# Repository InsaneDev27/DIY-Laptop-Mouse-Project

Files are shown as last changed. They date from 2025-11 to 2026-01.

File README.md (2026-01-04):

# DIY-Laptop-Mouse-Project

The Laptop Mouse Project (LMP) is a DIY solution for discomfort caused by prolonged use of laptop trackpads. The LMP offers an ergonomic alternative to a typical mouse or trackpad and clamps to the side of laptops for stability and comfort. It is mostly 3-D printable, and all electronics can be found online.

\
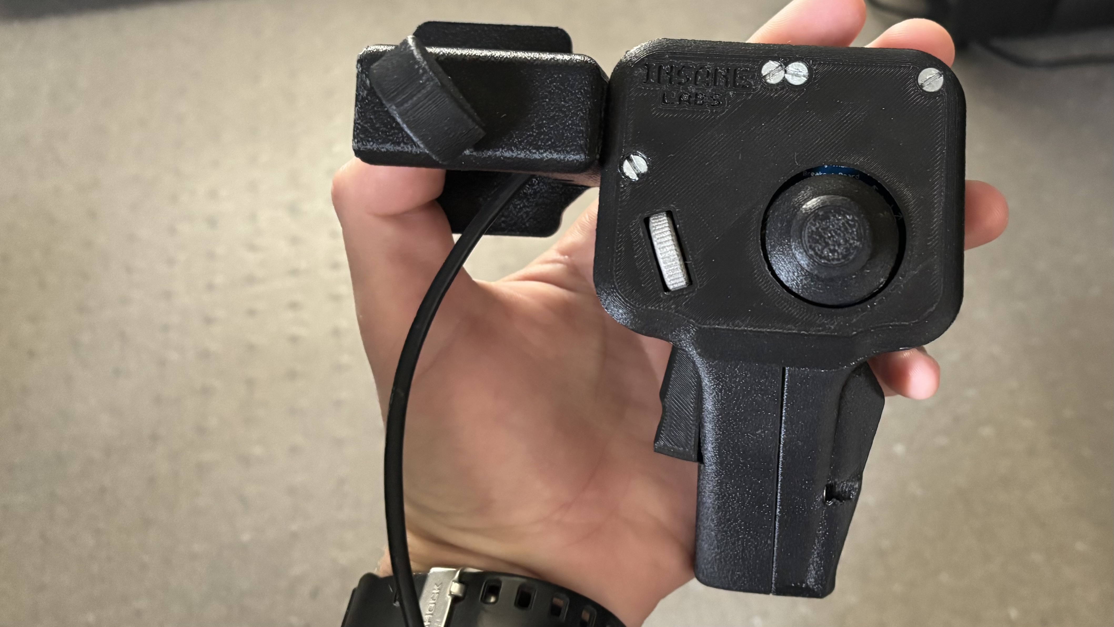
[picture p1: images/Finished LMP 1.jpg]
Finished LMP 1

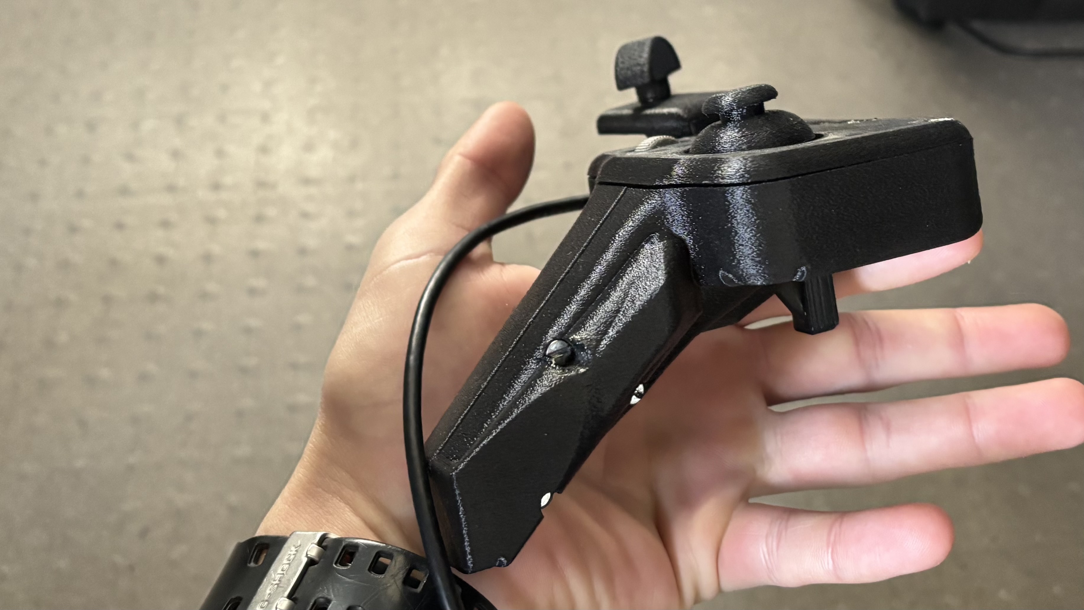
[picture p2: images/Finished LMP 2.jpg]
Finished LMP 2

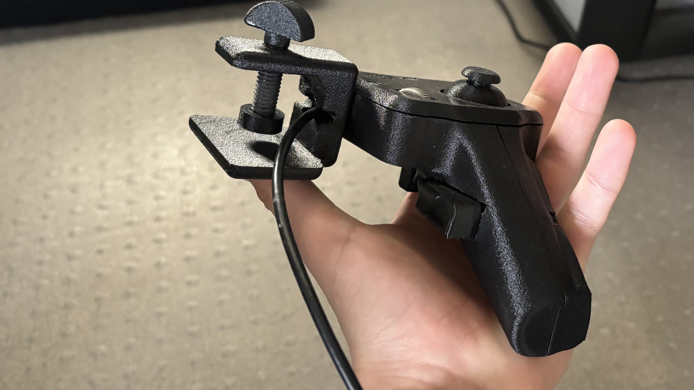
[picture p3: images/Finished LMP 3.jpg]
Finished LMP 3


## Intro

I began this project because I have always been extremely disatisfied with laptop trackpads. Trackpads cause my wrist discomfort after prolonged use, especially when I am using my laptop on my lap. I realized that I am not the only one that feels this way, and set out to design a suitable alternative that would fix this discomfort. I hope that my solution will work for you as well.

## Required Skills

 - Familiarity with 3-D printing and Slicers
 - Cleaning up 3-D prints, removing supports, and resolving small tolerance issues
 - Soldering
 - Familiarity with 3-D printing companies such as PCBWay or JLCPCB (only if your printer cannot print the Scroll Wheel strong enough)
 - Some knowledge of programming in Python

## Parts List

 - 1x  Raspberry Pi Pico  (example: [Pico](https://www.pishop.us/product/raspberry-pi-pico/?src=raspberrypi))
 - 1x  Joystick  (designed only for: [adafruit_joystick](https://www.adafruit.com/product/512))
 - 1x  5mm Mouse Rotary Encoder  (example: [kalih_red_5mm_mouse_encoder](https://www.aliexpress.us/item/3256806292223943.html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))
 - 2x  4-Pin Push Buttons 6x6x5mm  (example: [amazon_button_pack](https://www.amazon.com/Momentary-Pushbutton-Switches-Breadboard-Electronic/dp/B09R42NFGN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))
 - 3x  #4 ¾” Flathead Phillips Machine Screws
 - 4x  #4 ½” Flathead Phillips Machine Screws
 - 1x  USB-A to Micro USB Cable (3 ft, but can be ordered different length to fit preferences)
 - Solid Single-Core 22 AWG Wire

Estimated Total Cost (with shipping to the US and outsourcing the Scroll Wheel production): $35 to $60

Cost Breakdown (including shipping to the US):
 - $10 - Resin Printed Scroll Wheel (this is for resin printing on PCBWay, and includes shipping to the US) (I ordered Stainless Steel SLA on PCBWay for added strength and visual appeal, which cost $32)
 - $12 - Adafruit Joystick
 - $4 - 5mm Rotary Encoder (possible to harvest from an old mouse)
 - $8 - Raspberry Pi Pico
 - $5 - ~200g of PLA filliment

## Tools List

 - 1x  Soldering Iron
 - 1x  Wire Stripper (22 gauge capable)
 - 1x  Needle-Nose Pliers
 - 1x  Phillips Screw Driver
 - 1x  ⅜” - 16 or ⅜” - 24 Outside Diameter Thread-Tap and corresponding Inside Diameter Tap
 - Small Files
 - X-Acto Knife/Carving Tools
 - Automotive Picks (recommended for removing supports in tight places)

## Instructions

### Electronics
   
 #### Wire Lengths:
 
  - 1x  RMB  1.25”
  - 1x  LMB  1.75”
  - 2x  Button Ground  2.50”
  - 3x  Rotary Encoder  3.00”
  - 5x  Joystick  5.50”
 
 #### Pinout Diagram:

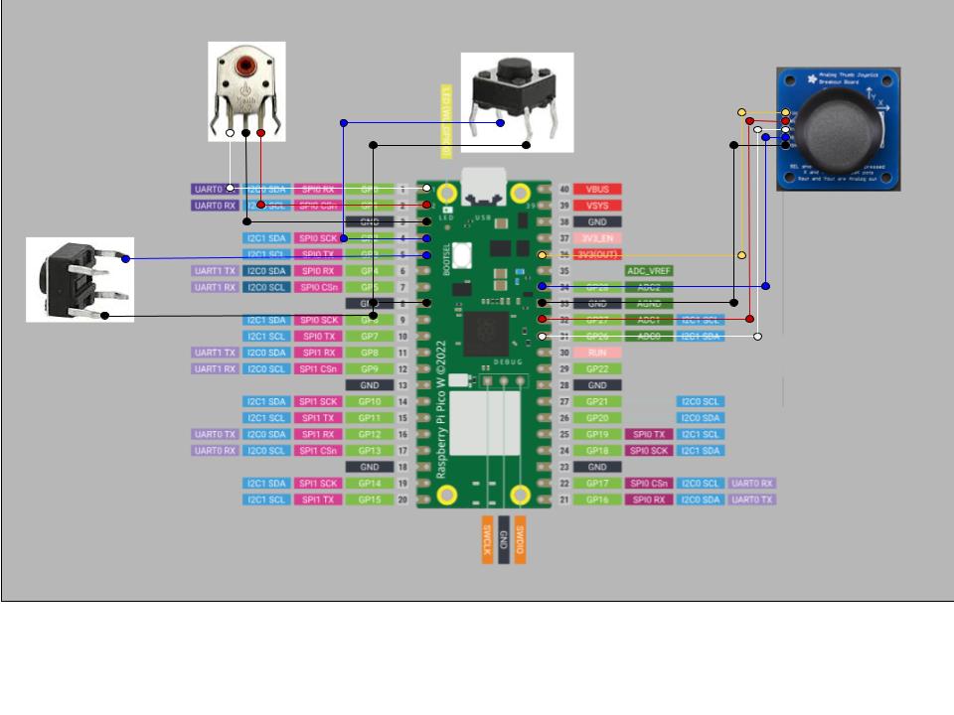
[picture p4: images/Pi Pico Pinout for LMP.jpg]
Project Pinout


NOTE: On the rotary encoder, there should be 2 legs on the sides that normally help align the encoder on a mouse board, but are not necessary. Cut these off, as they will interfere with assembly later and often cause confusion in the soldering stage.

Rotary encoder pins to cut off

NOTE: The ground wires from the left mouse button (LMB) and right mouse button (RMB) are connected in my diagram and images. I did this to consolodate the wire spead and because in a previous design other ground ports were blocked. However, if you would like to avoid having to solder the two wires together, another ground pin is located 13 pins down on the left.

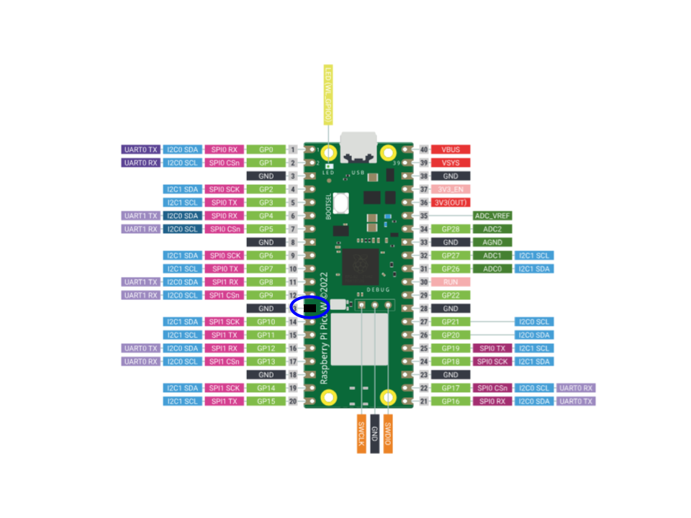
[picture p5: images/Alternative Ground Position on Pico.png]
Secondary ground location

 
 #### Final Soldered Assembly:

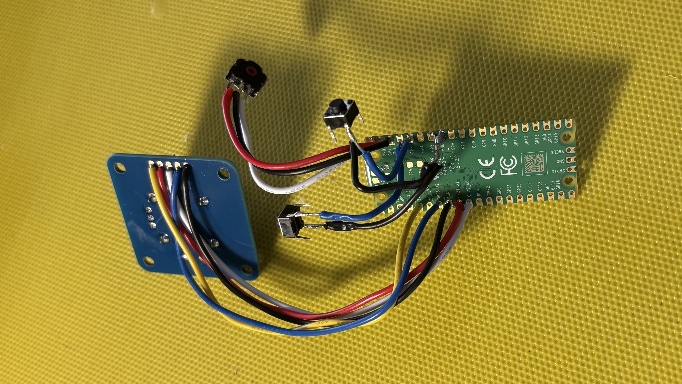
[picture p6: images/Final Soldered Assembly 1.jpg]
Final Soldered Assembly 1
 

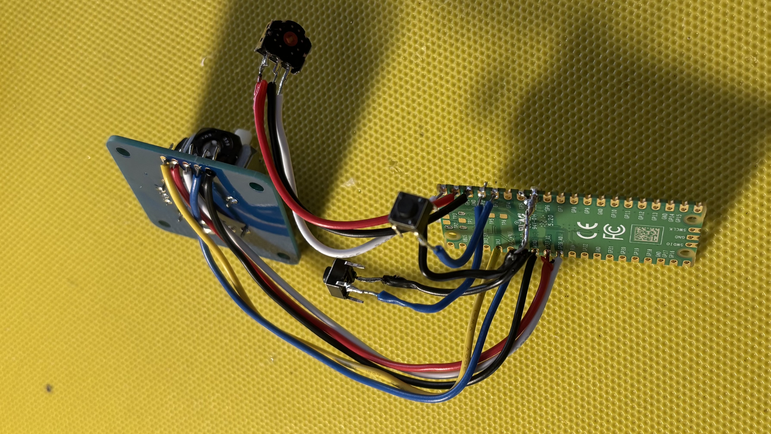
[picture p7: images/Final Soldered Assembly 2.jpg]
Final Soldered Assembly 2
 

### Code
   
 #### Configuring Raspberry Pi Pico:

 After everything is soldered to the Raspberry Pi Pico, connect the Pico to your computer. Navigate to the Pico in File Explorer, and drag and drop this file to the Pico's interal storage: [adafruit-circuitpython-raspberry_pi_pico-en_US-9.1.1.uf2](https://github.com/InsaneDev27/DIY-Laptop-Mouse-Project/blob/main/Code/adafruit-circuitpython-raspberry_pi_pico-en_US-9.1.1.uf2). This will initiate the installation CircuitPython onto the Pico, enabling the use of the Adafruit HID library ([more information on the Adafruit HID library](https://docs.circuitpython.org/projects/hid/en/latest/)) that allows the Pico to function as a mouse or other Human Interface Device.

 \
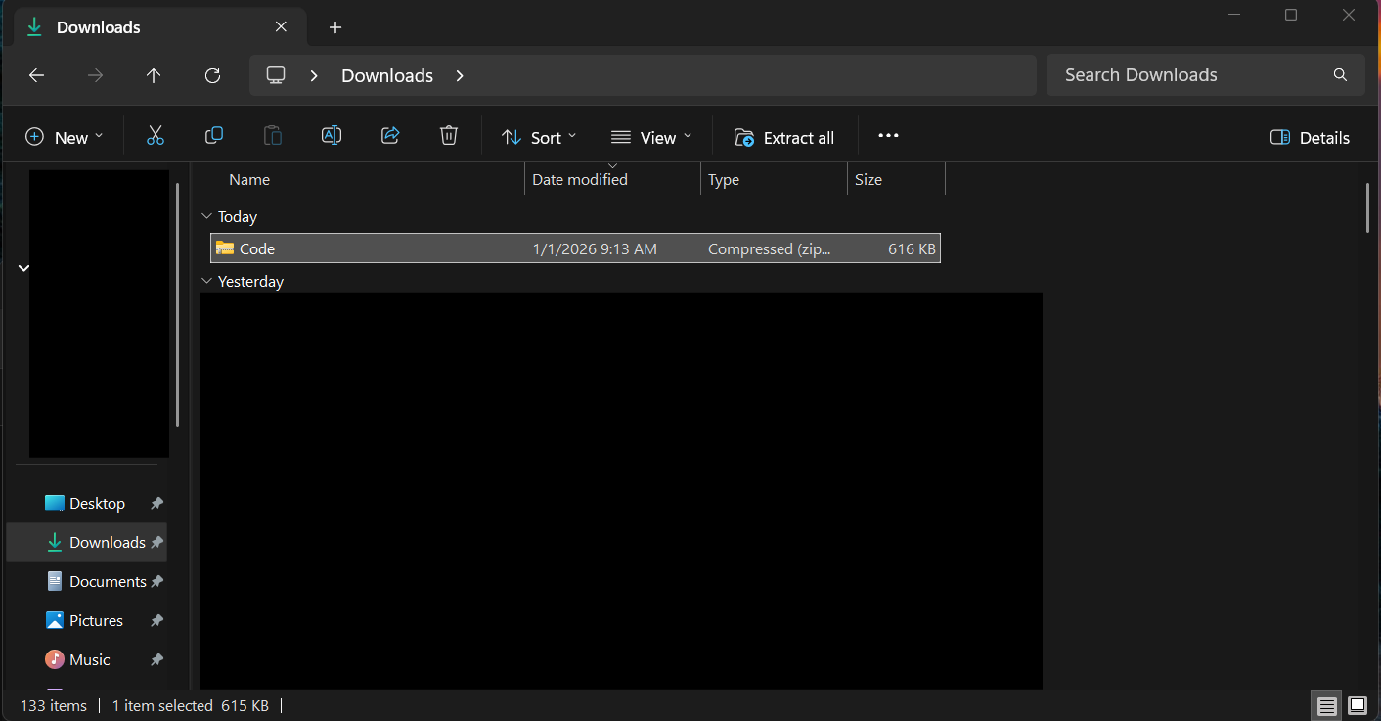
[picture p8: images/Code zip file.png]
Code zip file
 
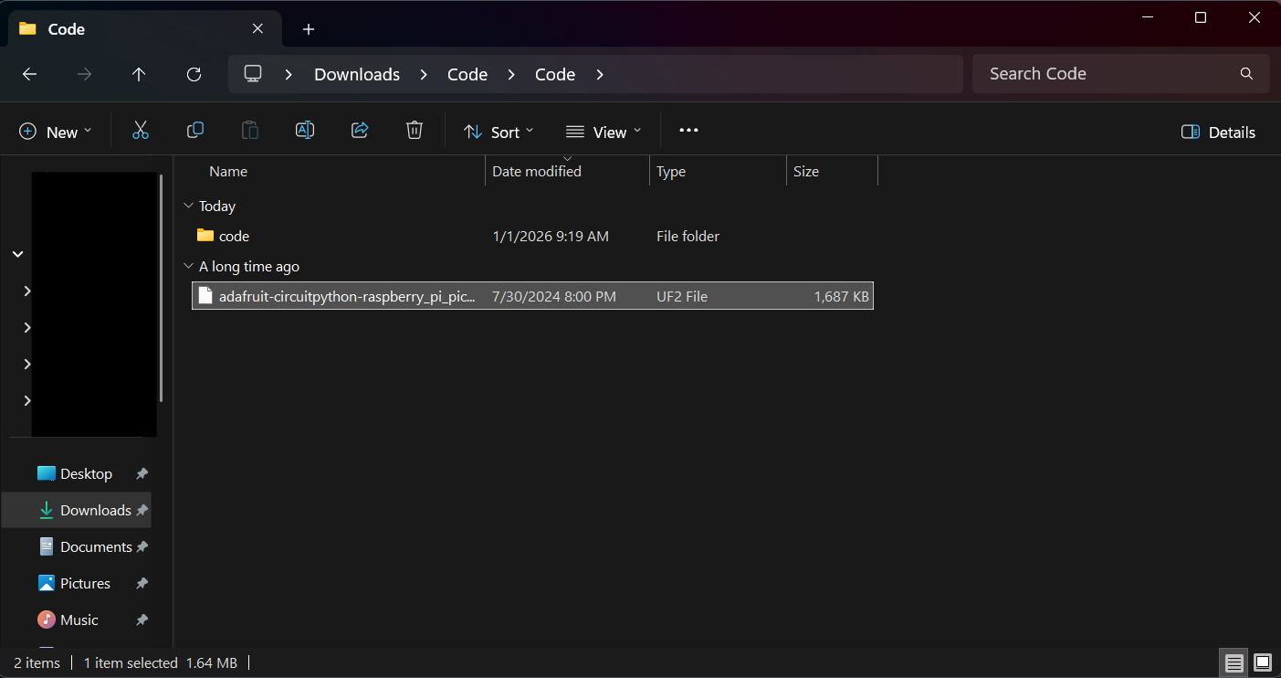
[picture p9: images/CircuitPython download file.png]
CircuitPython download file
 
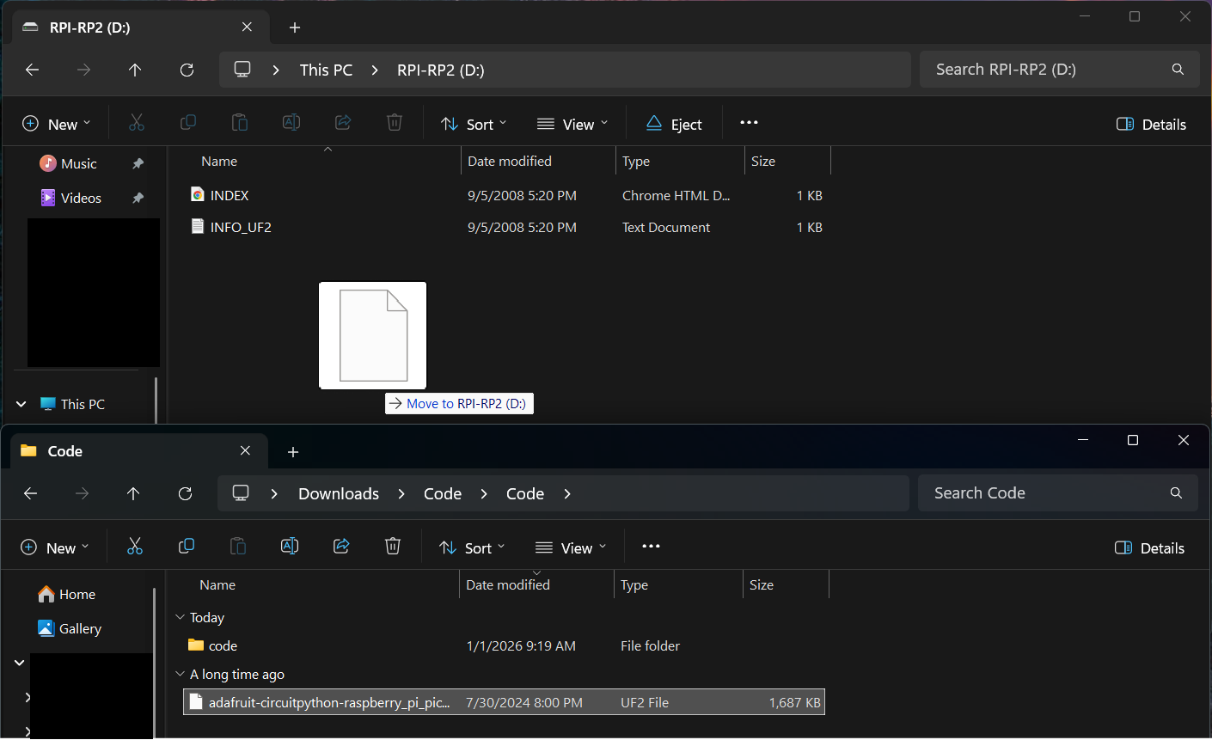
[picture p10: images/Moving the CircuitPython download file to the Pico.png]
Installing CircuitPython on Pico
 
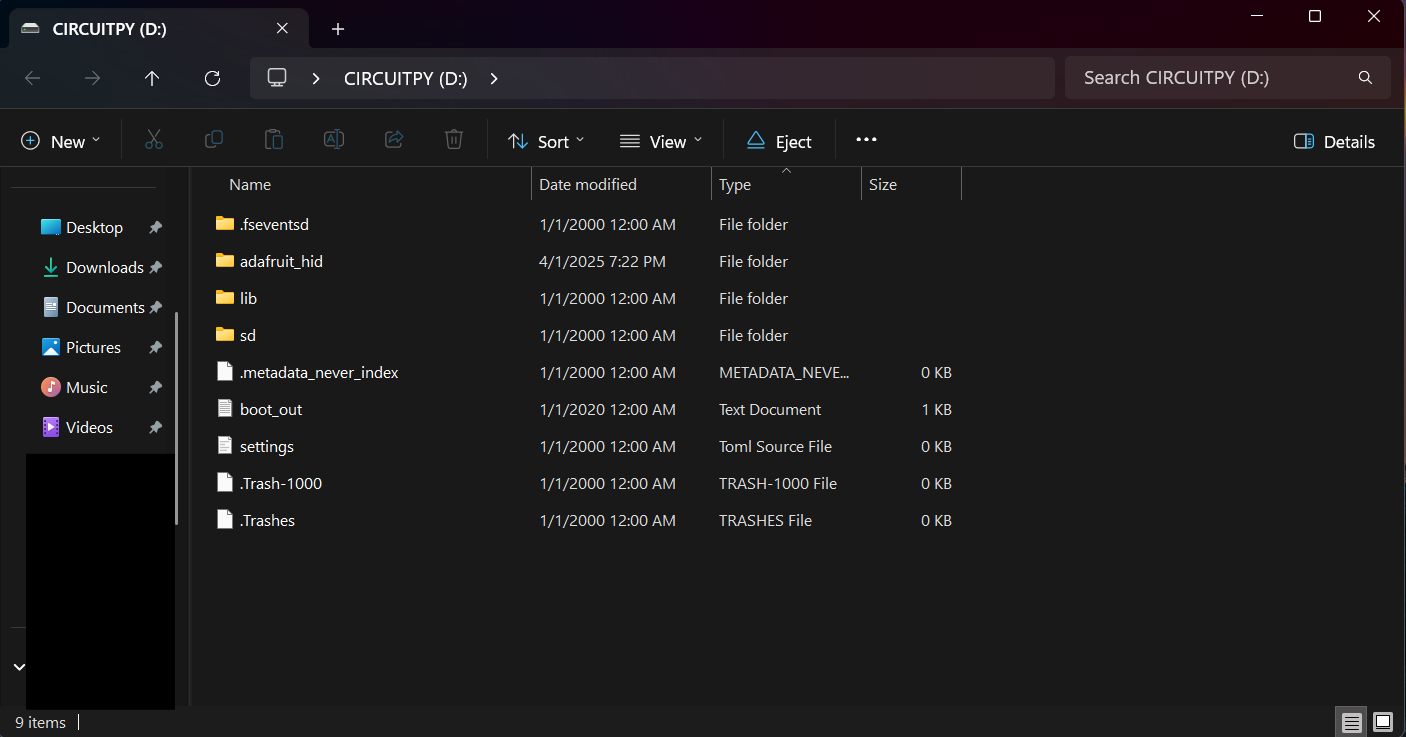
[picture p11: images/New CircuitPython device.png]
New CircuitPython device
 

 Once CircuitPython is installed, drag and drop the contents of the [code](https://github.com/InsaneDev27/DIY-Laptop-Mouse-Project/tree/main/Code/code) folder onto the Pico, making sure that main.py is not buried in a folder on the Pico.
 \
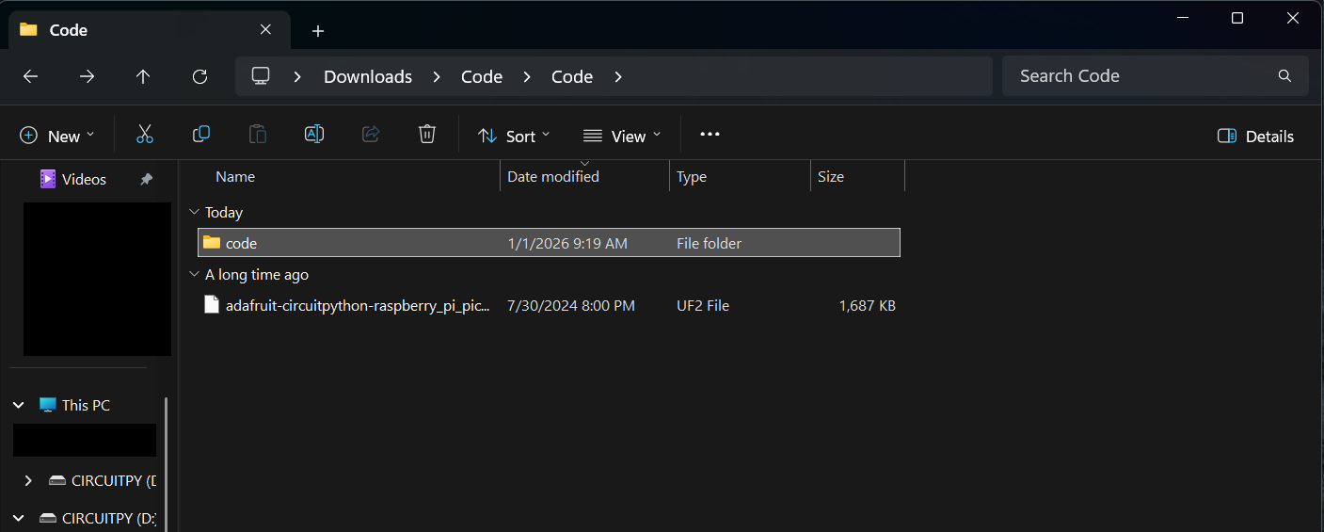
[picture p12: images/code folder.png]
code folder
 
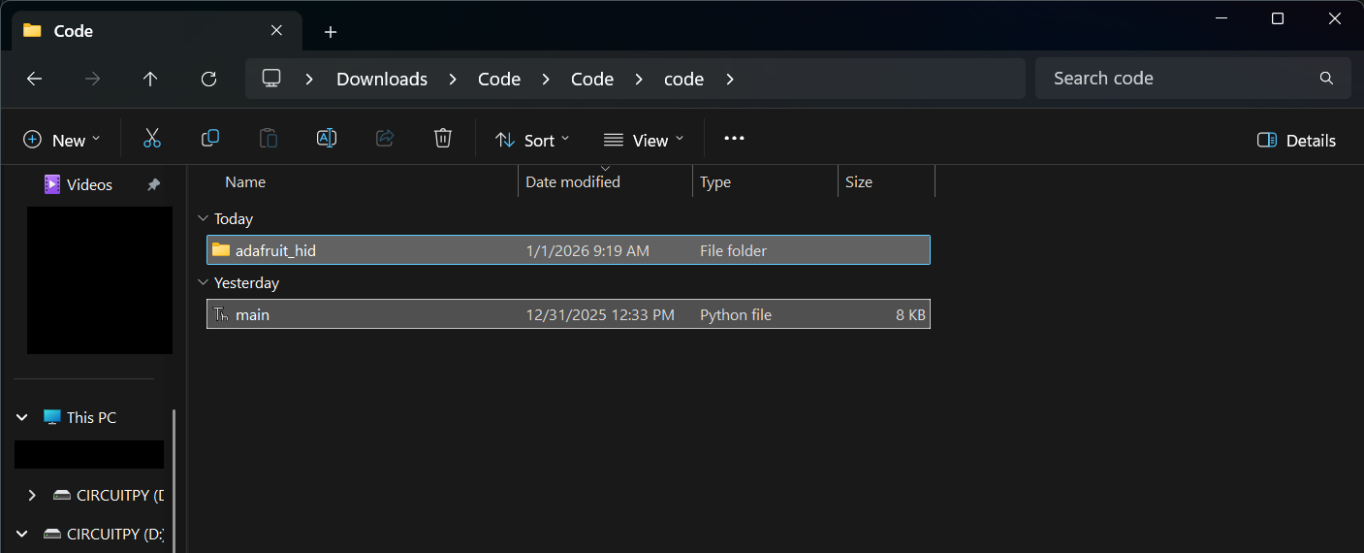
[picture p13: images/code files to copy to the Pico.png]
Code files to copy
 
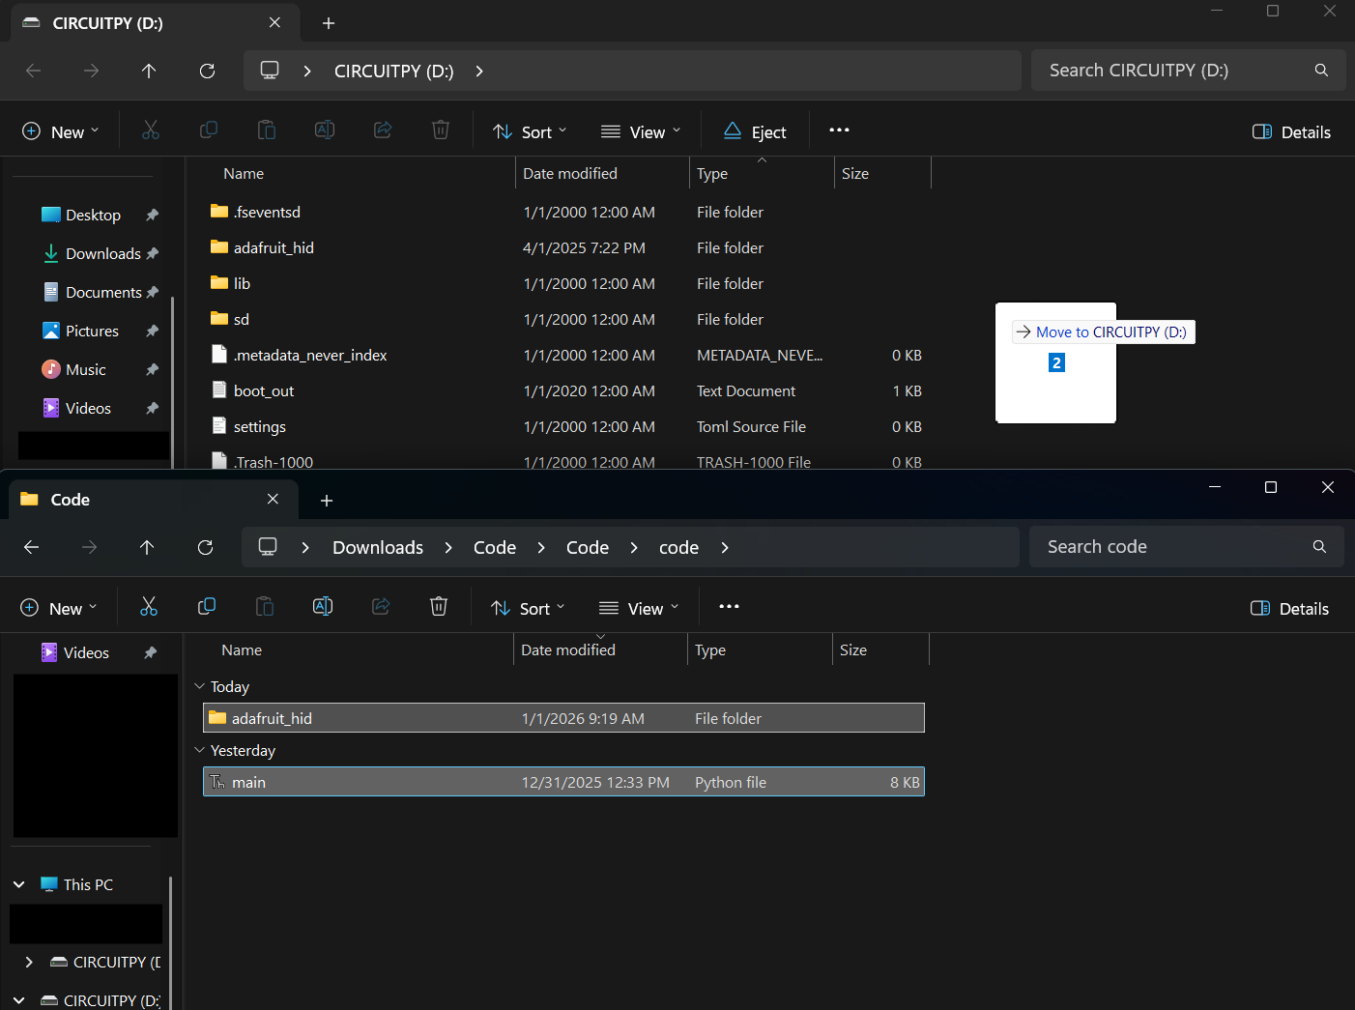
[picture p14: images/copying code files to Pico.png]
Copying code files to Pico
 

 Now, eject the Pico, disconnect and reconnect it to the computer. The program should run on startup, allowing you to check that all electronics and code functions properly. If something on the thumbstick was soldered incorrectly, the cursor on your computer may start to move uncontrollably. If this occurs, disconnect the Pico from your computer without ejecting (as long as nothing is actively being written to the Pico's memory, this should not damage the device), and check that your connections match the diagram. Most of the code should be plug-and-play, but you may want to adjust the scroll wheel sensitivity and settings or change/configure commands (RMB+LMB => your function).
 To do this, open the "main" file on your Pico. Most of the variables and code related to the Scroll Wheel is to implement a sort of psuedo-fast-scrolling, which is supposed to detect when the user scrolls in rapid succession and boost the effect of each scroll similarly to touchscreen scrolling. You can simply delete or comment out all of this code if you do not want this functionality, and tune the sensitivity manually. If you would like to investigate the psuedo-fast-scrolling, however, start by uncommenting the print file.

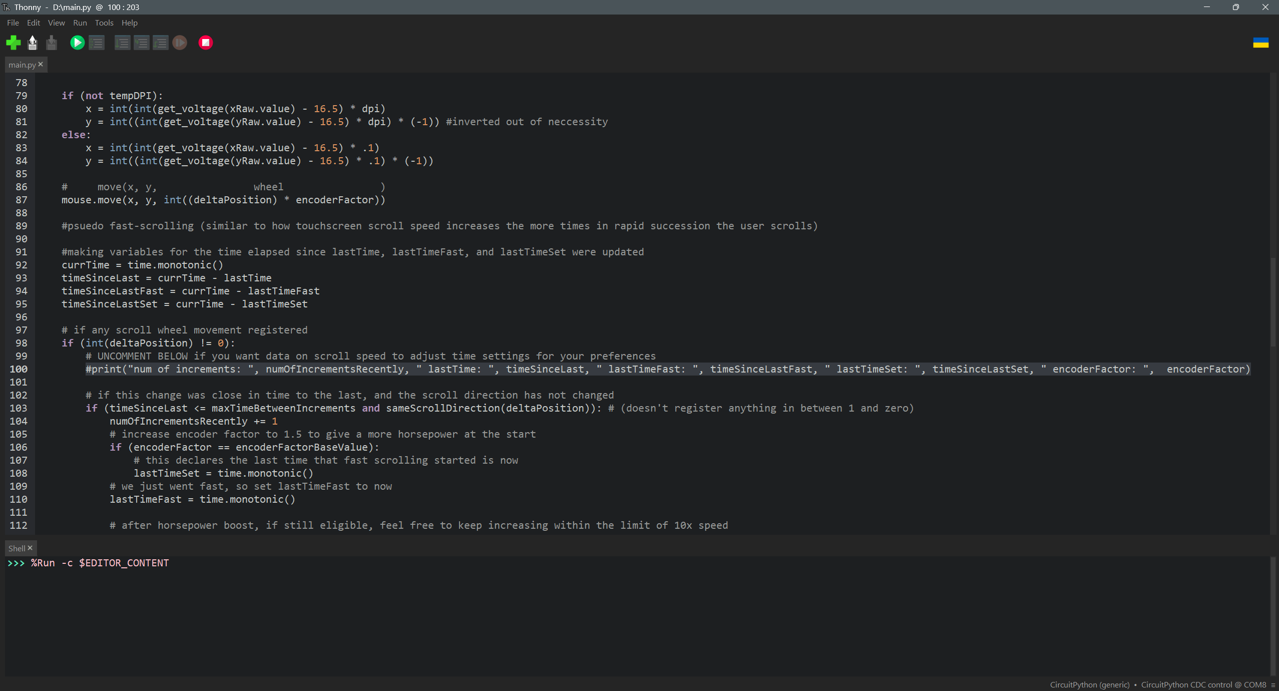
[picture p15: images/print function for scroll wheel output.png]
Uncommenting print
 

  In the output, `numOfIncrementsRecently` corresponds to the amount of physical clicks when the rotary encoder detects rotation. It is reset every time sensitivity is increased, and it is used to determine the amount of clicks that pass between each increase in speed. `if([numOfIncrementsRecently > 1] && [timeSinceLastFast <= maxTimeBetweenFastScroll]) {//increase sensitivity}`. `lastTime` refers to the last time the rotary encoder detected rotation (physical click). `lastTimeFast` is the last time that criteria was met to scroll fast. `lastTimeSet` tracks the last time fast scrolling was initiated. This is used as a secondary check to determine inelegibilty for scrolling fast. `if([(lastTimeFast > maxTimeSinceLastFast) && (lastTimeSet > 1)] || [scroll direction changed]) {//ineligble to go fast}`. Finally, `encoderFactor` is the sensitivity of the scroll wheel. Using these outputs, you can adjust `maxTimeBetweenFastScroll`, `maxTimeSinceLastFast`, `encoderFactorBaseValue`, the horsepower boost value (originally set to +=1), and how the `encoderFactor` gets increased. My settings work for my hand and my scroll speed, but they might not work for everyone. Additionally, the way I chose to implement pseudo-fast-scrolling may not be the best or most efficient way to accomplish this, and you can rewrite the whole system if you so desire.

  It is also fairly commmon for the scroll direction to be accidentally inverted due to the two outer pins of the rotary encoder being connected to the Pico opposite of the diagram. In this case, find the `encoder` variable declaration, and switch the order from `rotaryio.IncrementalEncoder(board.GP0, board.GP1, 1)` to `rotaryio.IncrementalEncoder(board.GP1, board.GP0, 1)`. 
  
 Lastly, the commands can be customized. Originally I have it set so that when all three buttons are pressed simutaneuosly (LMB+RMB+CMB), thumbstick sensitivity (similar to DPI) is cycled, and when only left and right click are pressed together, sensitivity is set to low to make fine motion easier. However, these commands can be altered or removed, and are located towards the bottom of the main function.

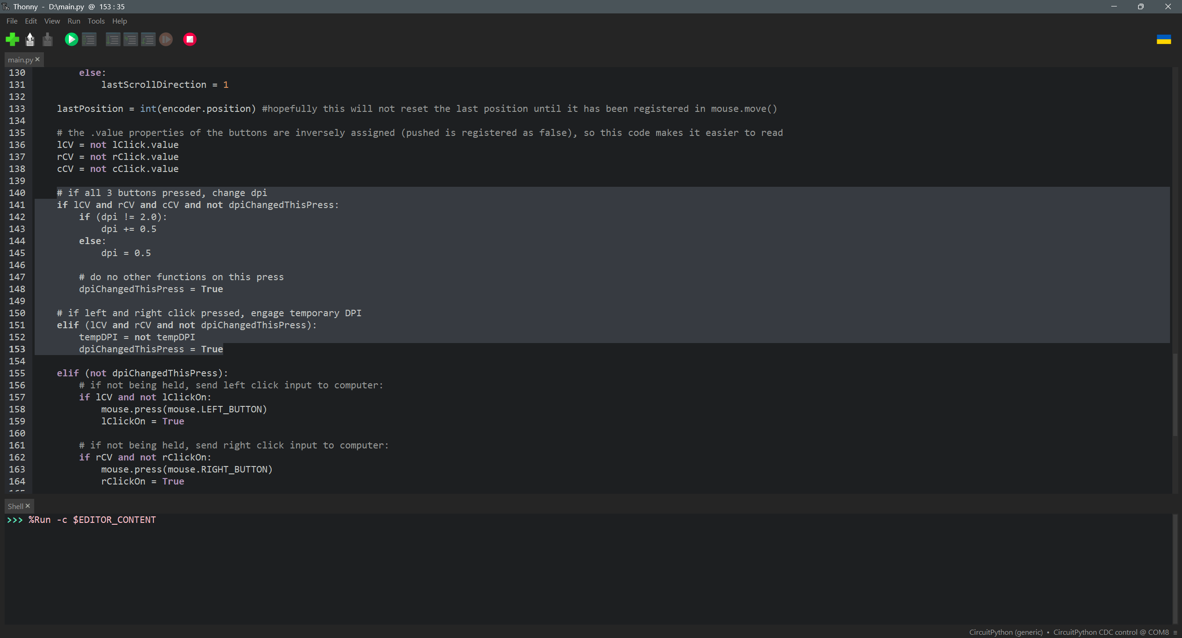
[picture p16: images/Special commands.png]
Code for special commands
  

### 3-D Printing

 #### Parts List:
 - Cap for clamp port on Left Body
 - Clamp Body
 - (optional) Clamp delete plug for Left Body
 - Clamp Screw
 - Clamp Screw Bottom - Female
 - Clamp Screw Bottom - Male
 - Plunger Extender for Right Click Trigger
 - Left Body
 - Right Body
 - Scroll Wheel
 - Thumbstick Cap
 - Top Cover
 - Left Click Trigger
 - Right Click Trigger
 
 #### 3-D Printing Notes:
 For the most part, the 3-D printing process is fairly standard and straightforward. All of the STL files can be found in the [STLs folder](STLs). However, there are a couple of settings and suggestions that I found helpful. The first is Fuzzy Skin. On most of the parts in the project, I used fuzzy skin to hide layer lines and provide a more premium appearance to the end-result. This does take a little more time and slightly more filament, but it was worth it for me. Below are the Fuzzy Skin settings that I used with my Elegoo Neptune 3 Pro.

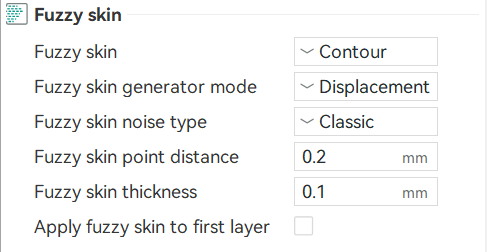
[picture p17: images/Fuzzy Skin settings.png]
Fuzzy Skin settings
 

 I enabled the Fuzzy Skin on every part minus the two triggers. My second suggestion is to print the Clamp Screw with 100% infill. I could not figure out how to add threads to the screw in my modelling software, necessetating thread tapping in post processing. When I tried to tap the Clamp Screw without 100% infill, the outer walls stripped from the infill and totalled the part. The Clamp Body, however, because it needs inside diameter tapping, does not need to be printed in 100% infill. Furthermore, if the Clamp Body is printed in 100% infill, it will likely not have the same strength as less infill. If you find a way to add threads to the Clamp Screw and Clamp Body models, you can disregard this suggestion and print with your normal infill settings.

 I would also reccomend printing with less walls on the Thumbstick Cap to allow the slot to flex for a tight interface with the thumbstick shaft. If you would prefer, you can use any aftermarket thumbstick cap as long as you can make it fit with the Top Cover.

 Finally, my last suggestion is to outsource the printing of the Scroll Wheel unless you have a resin printer. My experience with FDM printing the Scroll Wheel in PLA was that it always broke along the layer lines of the hex axle due to rotational force when attached to the rotary encoder. After many failed attempts, I ordered the Scroll Wheel off of PCBWay to be printed in Stainless Steel. While this was not very budget-friendly and the cheaper resin printing option would probably be strong enough, I did not want any doubt of success and prefered the premium quality of metal.

 I also want to remind you that 3-D printed tolerances are not universal, and the dimensions that worked with my printer and filament may not work with your setup. Likewise, some post processing and tolerance adjustments are warranted. I printed everything on an Elegoo Neptune 3 Pro with black eSUN PLA+, but even if you have the same setup, some differences are inevitable.
 
 Lastly, if you would like to build the project without the clamp, print the "Clamp delete plug for Body - M" instead of the clamp parts, and disregard the clamp assembly section below.

 #### Post-Processing and Tolerancing:
 **Left Body**

Begin by removing support material as usual. Then, use a spare 4-pin pushbutton to test fit both the left and right click button slots, and remove material as needed. Pay attention to the thumbstick base slot, as this often gets clogged with support material. Finally, test fit with thumbstick if possible.

\
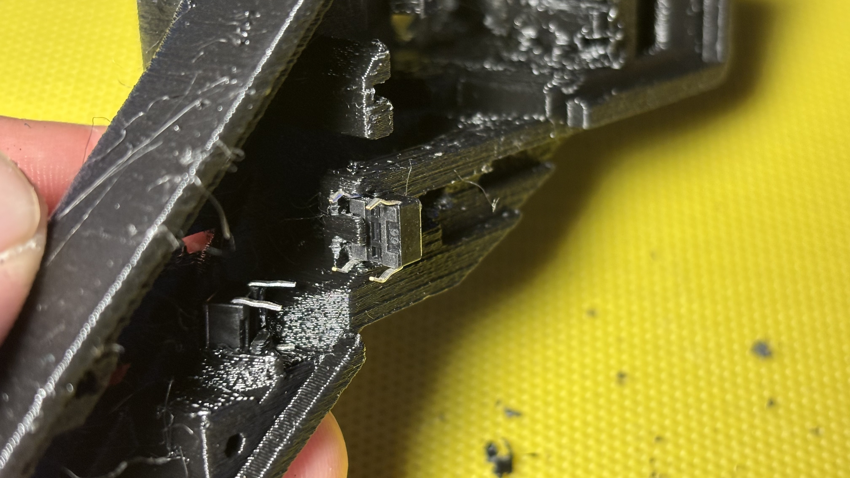
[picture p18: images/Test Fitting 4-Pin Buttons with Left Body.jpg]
Test fitting left and right click 4-pin push buttons with Left Body

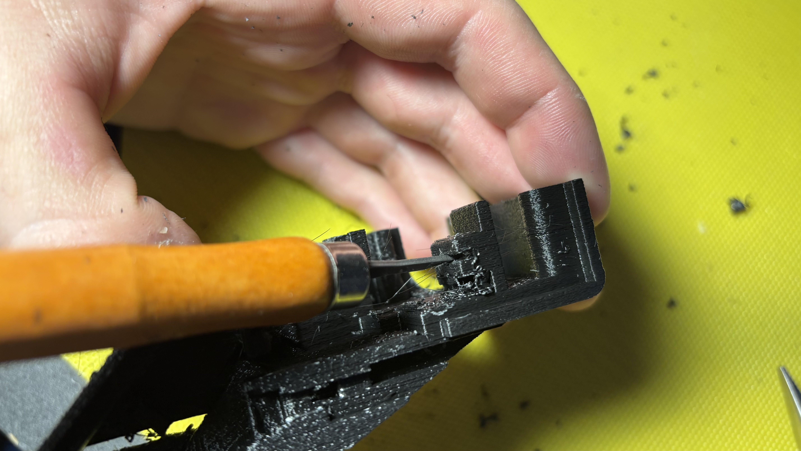
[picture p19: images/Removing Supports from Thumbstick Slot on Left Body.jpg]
Cleaning out thumbstick base slot on Left Body

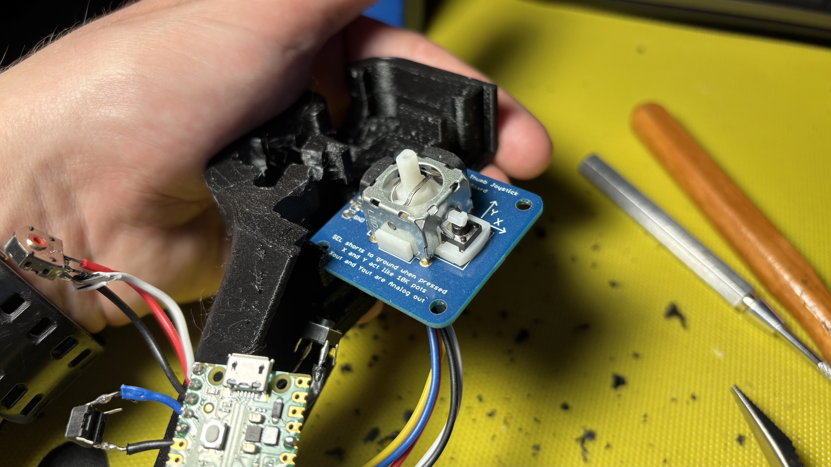
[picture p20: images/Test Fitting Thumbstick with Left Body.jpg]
Test fitting thumbstick with Left Body


Completed Left Body:\
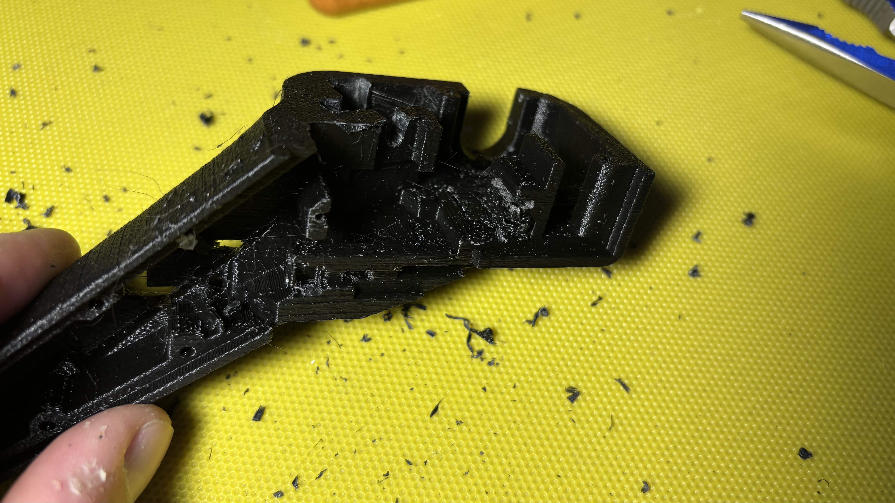
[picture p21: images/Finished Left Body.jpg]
Completed Left Body


NOTE: Avoid filing and removing material from anywhere that will be visible on the completed assembly, as this will likely result in discoloration that may be difficult to fix.

**Right Body**

Repeat the process explained for the Left Body. Pay attention to the cylindrical region of the front (left click) trigger slot, as this is often a source of resistance. If needed, this can be filed square on both the Right Body and the Left Body.

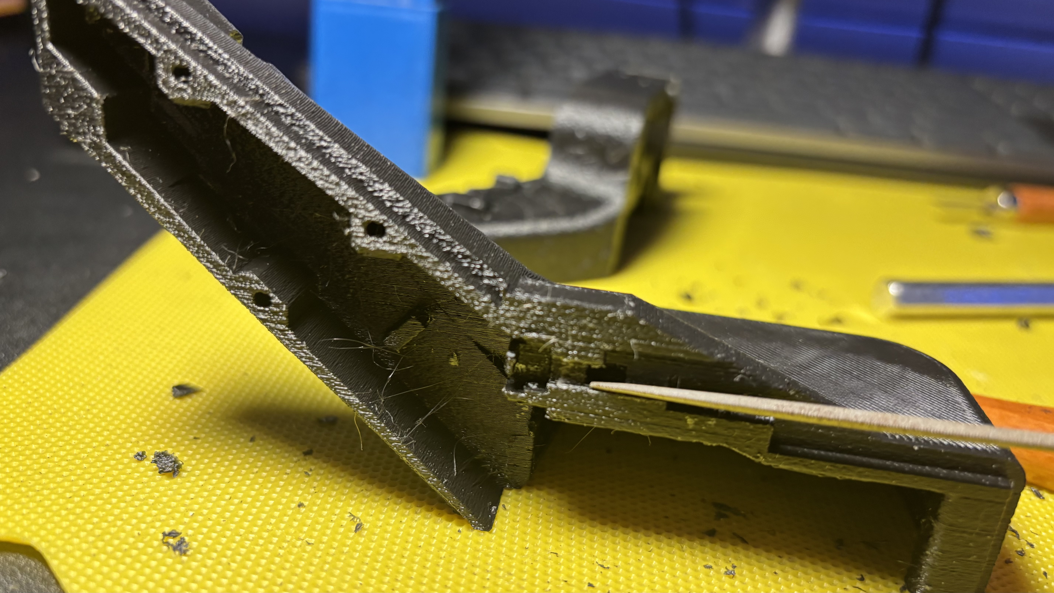
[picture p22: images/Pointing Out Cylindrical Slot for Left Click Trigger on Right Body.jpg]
Filing Left Click Trigger slot square


Completed Right Body:\
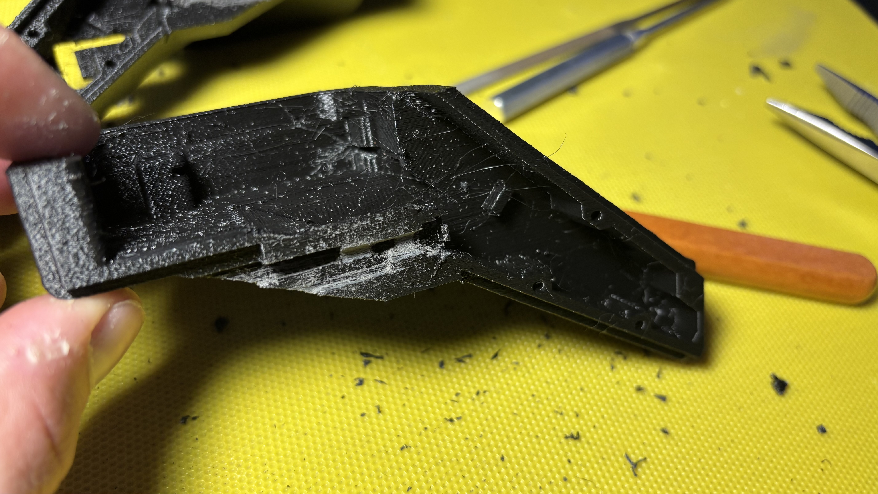
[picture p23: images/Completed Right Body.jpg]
Completed Right Body


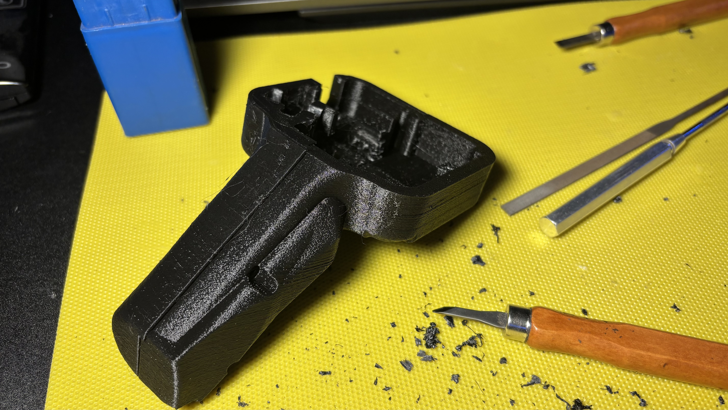
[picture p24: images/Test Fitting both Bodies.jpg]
Test fitting with Left Body


**Left Click Trigger**

Remove all support, file the cylindrical extrusion to remove any surface imperfections that result in drag. Test fit with each side of the body checking for resistance. Additionally, the wings of the trigger (the extrusions that stop the trigger from falling out) can be too long. Be sure thst these allow the trigger to slide long enough, and do not cause interference.

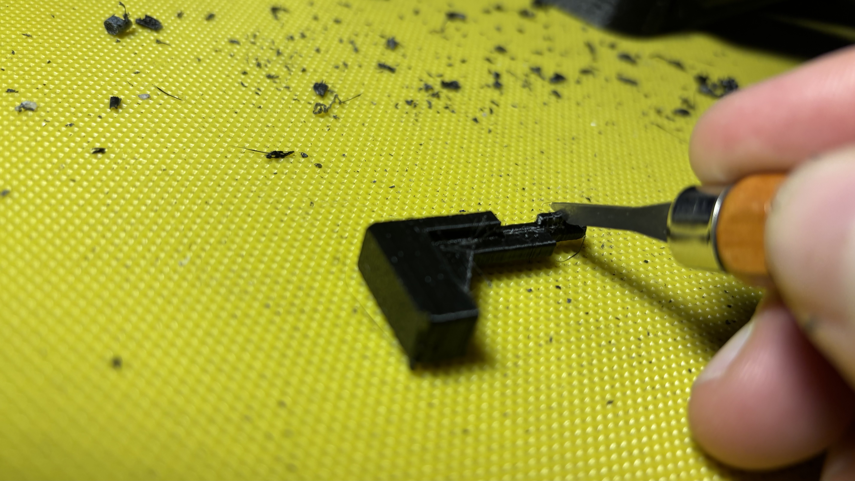
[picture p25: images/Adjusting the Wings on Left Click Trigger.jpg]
Adjusting wing on Left Click Trigger


Finally, assemble both sides, sanwiching the trigger, and make sure there is no new interference.

Completed Left Click Trigger:\
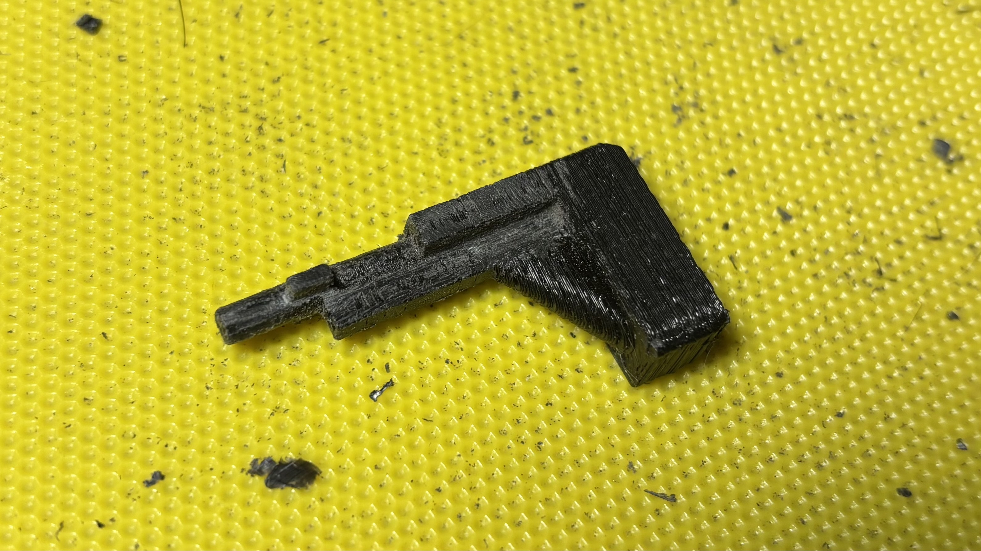
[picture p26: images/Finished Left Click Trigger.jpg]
Left Trigger done


**Right Click Trigger**

 When removing support, remember to not put stress on the pivot axle of the part and that the three small arms that anchor the plunger can get in the way of removing support. These support arms may not always be necessary, and can be removed if needed.

Look out for:\
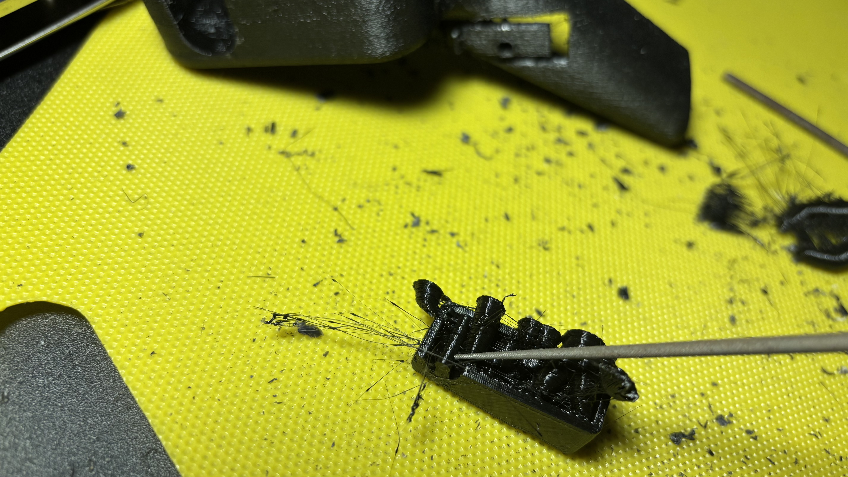
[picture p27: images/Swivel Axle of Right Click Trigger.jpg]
Point out swivel arm on Right Click Trigger

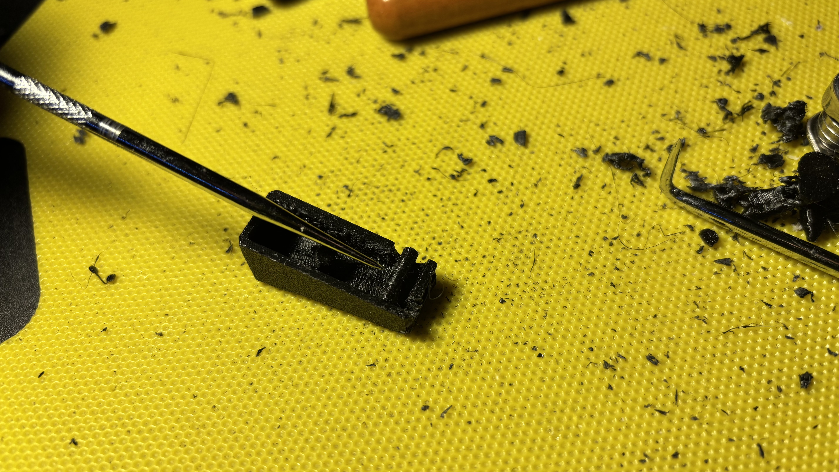
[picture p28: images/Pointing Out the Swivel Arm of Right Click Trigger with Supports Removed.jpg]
Point out swivel arm on Right Click Trigger (supports removed)


The small arms:\
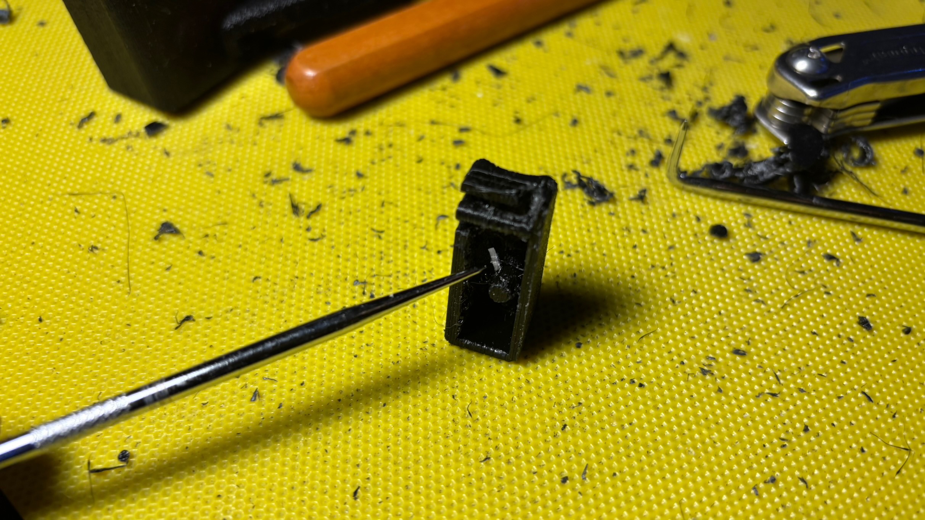
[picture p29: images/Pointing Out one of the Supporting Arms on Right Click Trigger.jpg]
The three small arms

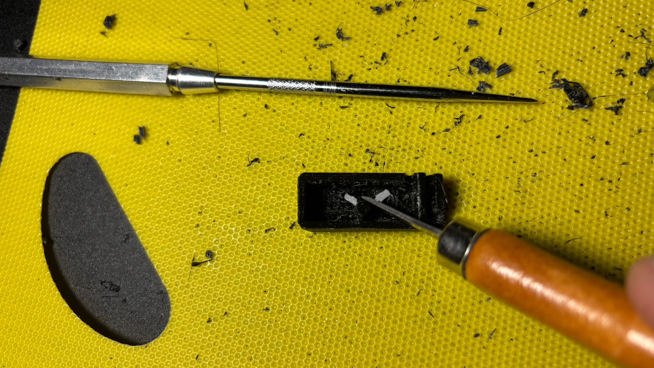
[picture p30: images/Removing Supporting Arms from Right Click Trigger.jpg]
Mock-removal of one small arm with knife


After the basic support removal, file down the inside top edge of the part until all suport residue is gone, file down the plunger, then test fit with the Left Body, and remove material from both parts as needed.

Completed Right Click Trigger:\
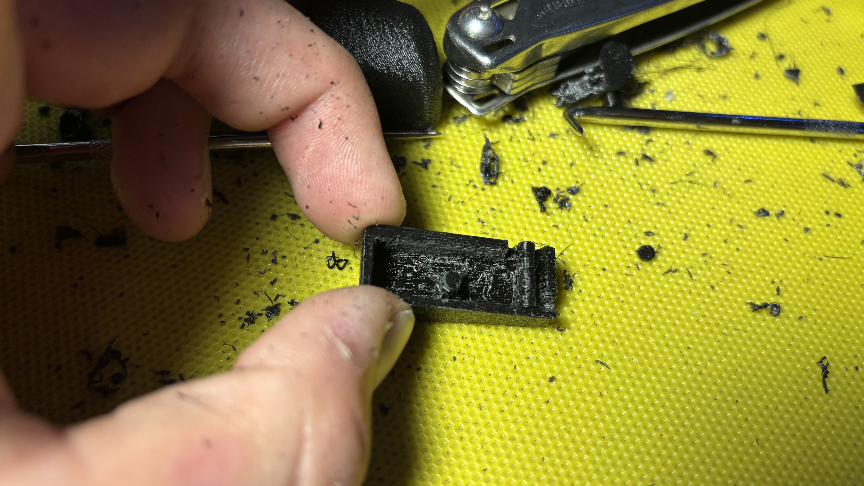
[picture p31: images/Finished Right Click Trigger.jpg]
Finished Right Click Trigger


\
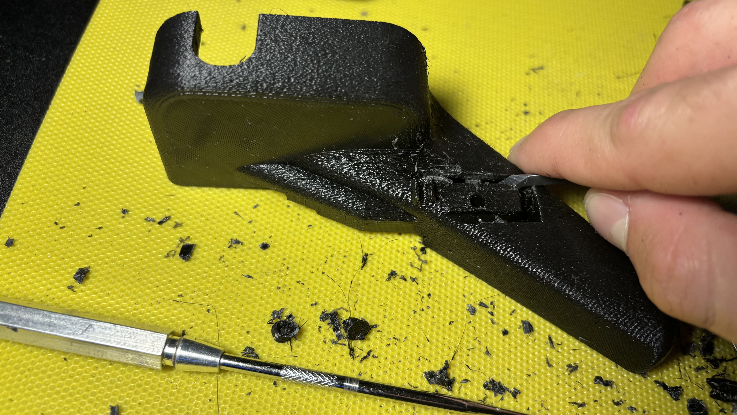
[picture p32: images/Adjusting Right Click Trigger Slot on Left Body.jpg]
Removing material from the Left Body on the top of the right click trigger slot

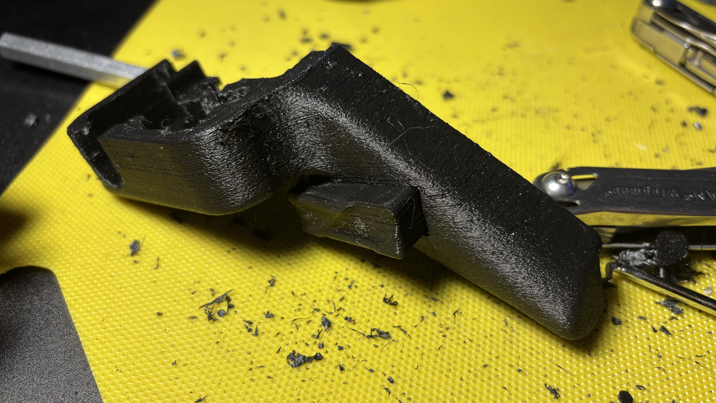
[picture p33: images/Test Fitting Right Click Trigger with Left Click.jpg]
Test fitting with the Left Body


**Scroll Wheel**

 Whether or not this was printed in metal, start by filing down the cylinder that supports the side opposite the hexagonal axle.

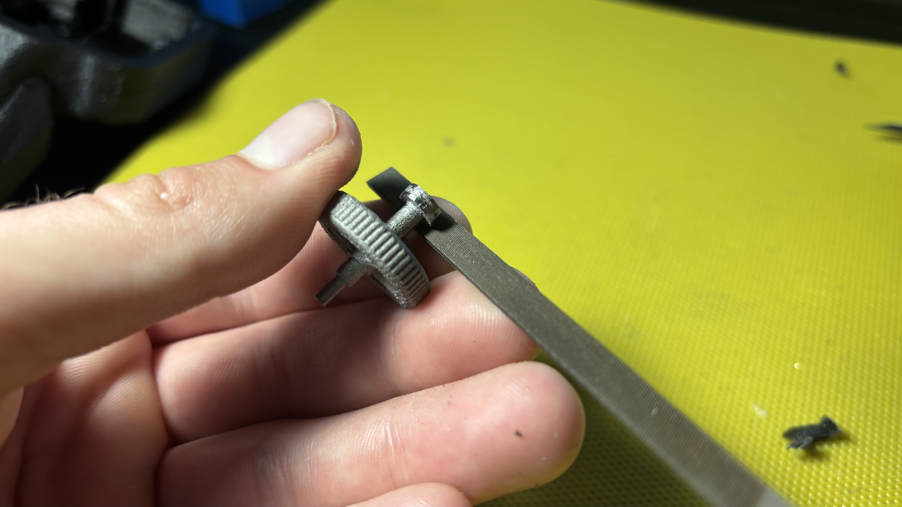
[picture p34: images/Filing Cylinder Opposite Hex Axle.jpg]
Filing down the cylinder opposite the hex axle


From there, test fit with the Left Body. If the part does not fit easily in the slot, start removing material from the Left Body. By the end, the Scroll Wheel should be able to spin in the slot with zero resistance from the Left Body.

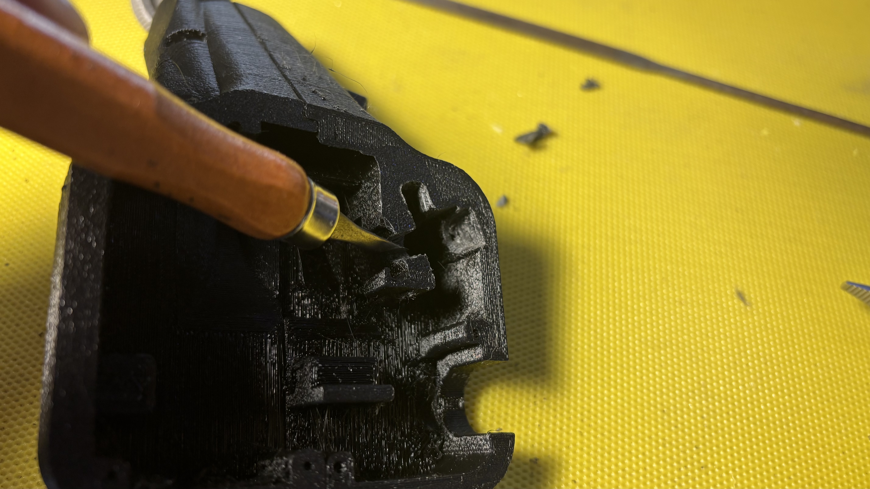
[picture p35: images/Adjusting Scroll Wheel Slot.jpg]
Removing material from scroll wheel slot


Then test fit the part with the rotary encoder. If much resistance is encountered, cease insertion immediately, remove and file down the indivual sides of the hex axle, trying to make sure material is removed from each side equally.

\
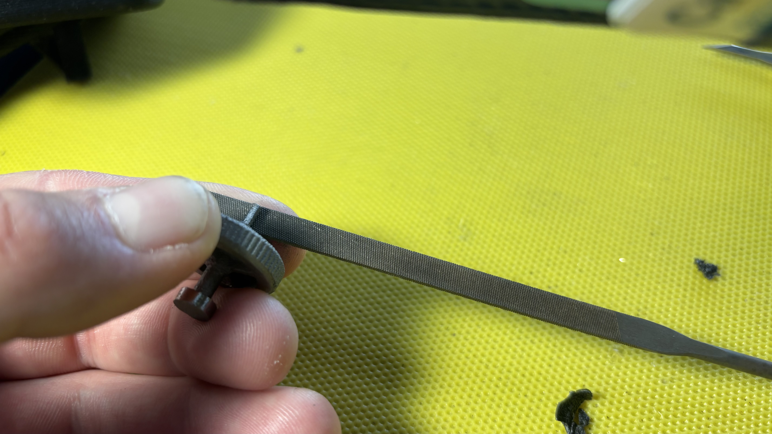
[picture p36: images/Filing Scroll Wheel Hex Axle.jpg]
Filing down scroll wheel axle

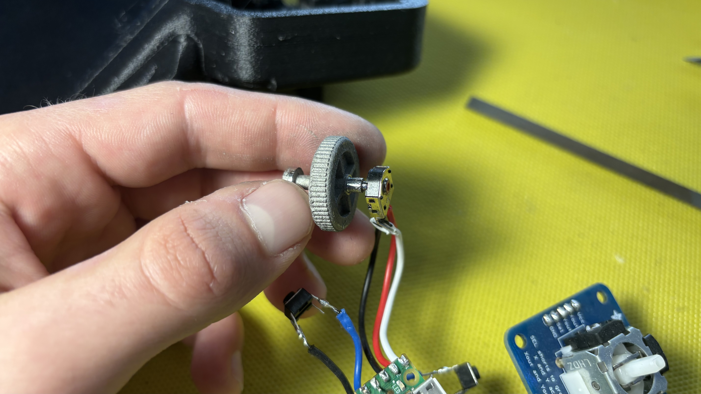
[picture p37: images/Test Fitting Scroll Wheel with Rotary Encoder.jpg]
Test fitting with rotary encoder


Test fitting upside down just to check fitment:\
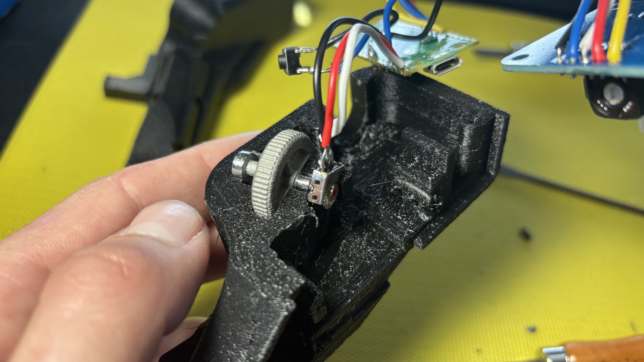
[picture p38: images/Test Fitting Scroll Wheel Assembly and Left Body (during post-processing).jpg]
Test fitting scroll wheel assembly with Left Body


Finished Scroll Wheel:\
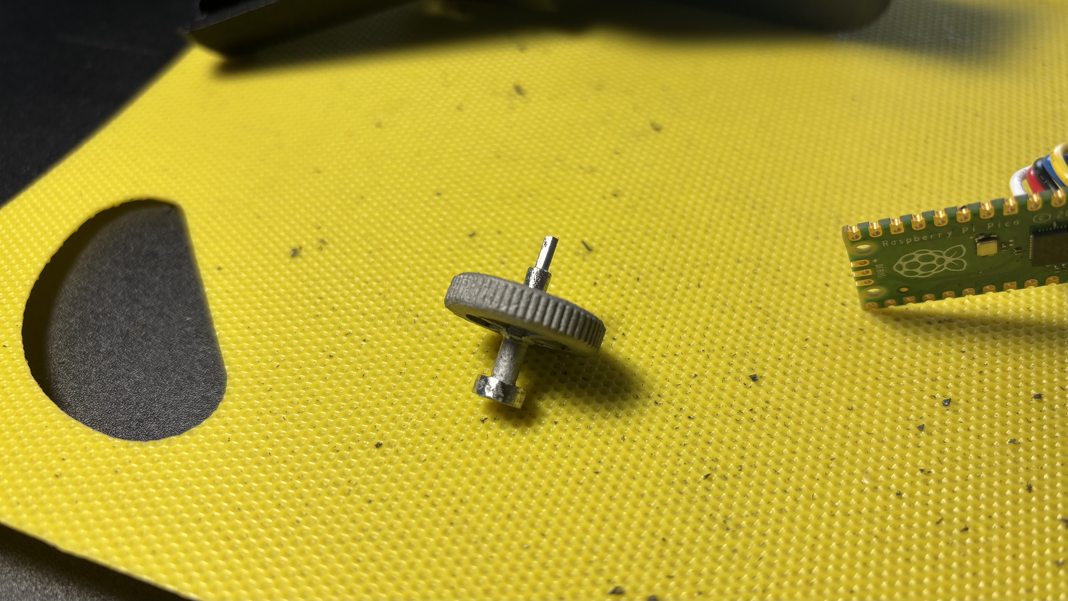
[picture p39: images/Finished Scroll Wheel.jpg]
Finished Scroll Wheel


**Clamp Body**

 When removing support, avoid putting pressure on the swivel where it connects to the body.

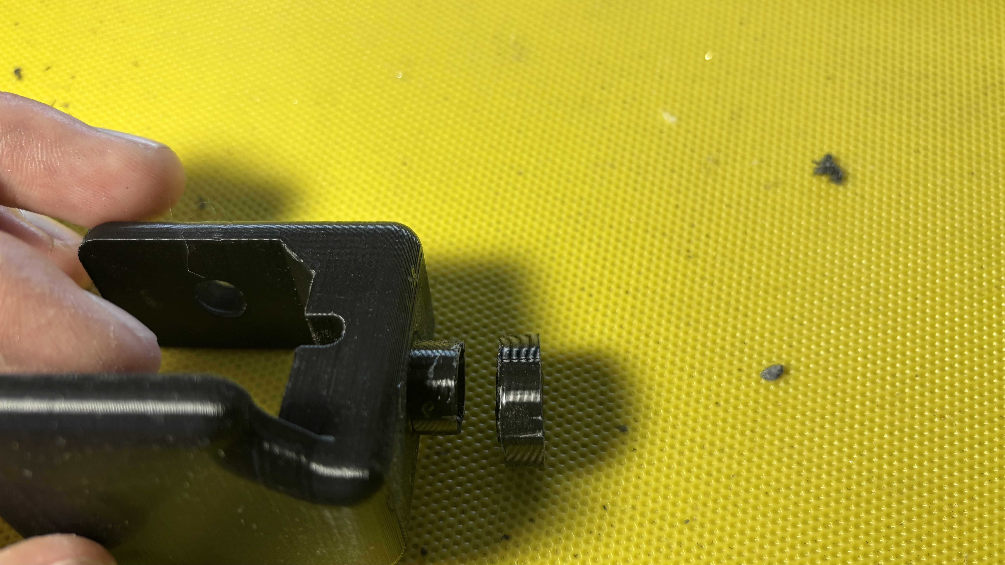
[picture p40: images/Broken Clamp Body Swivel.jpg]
Broken swivel


Once all support is removed, file down the inside face of between the top and bottom until mostly smooth.

Smooth inside face

Then, use a lighter or heat gun to recolor this segment. Avoid severely melting or warping the part.

\
Using lighter to recolor Clamp Body 1
Using lighter to recolor Clamp Body 2
\
Successfully recolored 1
Successfully recolored 2

Warped Clamp Body

After this, use a 3/8" - 16 or 3/8" - 24 inside tapping tool to thread the hole for the screw

\
Tapping Clamp Body
Completed Clamp Body

**Clamp Screw**

 Remove supports, file down the face under the head of the screw. Then, use a 3/8" - 16 or a 3/8" - 24 (must be same as used on clamp body) outside tapping tool to thread the screw. Use pliers to grip close to the tapping tool to prevent breaking the part. once your pliers run out of room above the tapping tool, position them below, and keep tapping. Don't worry about grooves left by the pliers, as the tapping tool will mostly fix this on the way back down.

Tapping with pliers close to tap

At this point, I can no longer tap with the pliers on top\
Reason for switched grip

If this occurs, switch to pliers under (switch-grip)\
Switched grip tapping

Tapping device at final position:\
Final position of the tapping device

Completed Tap:\
Finished tap

Clearing the hole:\
Clearing material from peg hole on Clamp Screw

Finally, use a lighter or a heat gun to recolor the screw. Use caution and quick sweeps, as this part warps very easily.

Recoloring Clamp Screw

You can now screw the Clamp Screw into the Clamp Body

Clamp screw and clamp body connected

**Clamp Screw Bottoms**

Remove supports as usual, lightly file the pegs to remove roughness and add chamfer to the pegs.

Lightly filed and chamfered pegs

On the female side, remove supports and make sure there is no residual material in the holes.

Finished Clamp Screw Bottom - F

Then gently place the two halves together, making sure not to completely attach the two sides as they should only go together with a lot of force. Remove material from the pegs until the first quarter of the pegs can go into the holes. Again, the fit is intended to be tight, and not be assembled until the final installation with the clamp screw. Once ready, screw the Clamp Screw into the Clamp Body, then run the center peg of the male Clamp Screw Bottom through the hole at the bottom of the Clamp Screw.

Clamp assembly with only Clamp Bottom - Male

Then line up the female side of the Clamp Screw Bottom with the male side and use pliers to press fit the sides together. If the female side starts warping excessively, gently remove using a knife or wedge to separate the parts, then file the pegs again. Repeat until fits properly.

\
Assembling the bottoms with Clamp Screw and Clamp Body
Completed Clamp Body assembly

 ### Assembly:
   
   Once all the parts are clean and free of supports, assembly can begin. I normally begin with the electronics and place the right-click button first, but feel free to install in whichever order makes the most sense.\
   NOTE: When bending wires and installing the electronics, it is typical to break a solder joint or two. Use care when bending the wires and have a soldering iron on standby just in case.
   
   #### Right Mouse Button
   I normally use my automotive picks to slot the button in place, and use another pick or an unwound paper clip to check if the button clicks as intended.

   \
   Slotting right click button in place using automotive pick (button not highlighted)
   Slotting right click button in place using automotive pick (button highlighted)
   
   Checking click with a paper clip:\
   Checking click with a paper clip
   
   Once in place, add super glue to where the button meets the plastic shell on the back right side of the button, making sure to avoid gluing the button open (where it refuses to depress).
   
   Gluing the right click button in place
   
   #### Raspberry Pi Pico
   
   After installing the left click, I normally slot in the Pico. Make sure that no wires are being pinched between the wall of the body and the Pico, and slot it in. Be sure the glue is dry if you are worried about the wires pulling the right mouse button out of place.
   
   Pico slotted in place
   
   #### Left Mouse Button
   Before installing the left mouse button, I usually bend the thumbstick under the body to get it out of the way. 
   
   Thumbstick bent under the body
   
   From there, it is a matter of bending wires and positioning the button in the slot. After this, install the thumbstick as described below, then put the two sides together and make sure the button and thumbstick align properly on both sides. If everything fits properly, you can use super glue to attach the button to the left side of the body if desired (be careful not to glue the two halves of the body together).

   Left click button installed

  #### Rotary Encoder
   
   Slide the scroll wheel assembly from earlier into the designated slot. This too should be relatively effortless once positioned correctly (which sometimes takes some time), and if it isn't, file the encoder slot in the Left Body down and then retry.

   \
   Scroll Wheel assembly being installed
   Scroll Wheel assembly fully installed
   
   #### Thumb Stick
   
   Slide into the slots on the left side of the body. Support material often gets clogged in there, so some clearancing may be necessary.
   
   Attaching the Thumbstick to the Left Body

   After this, try attaching the Right Body to check the fit of the left click button and the Thumbstick. The wires going to the Thumbstick board may need to be bent out of the way. When bending these wires, be sure to separate the power wire from the others. When this wire gets squeezed against the x and y axis wires it can sometimes cause interference that causes the cursor to behave erratically and uncontrollably.

   \
   Arranging wires before fitting together
   Attaching the two sides
   
   #### Attaching the Cable
   
   After all of the electronics are installed, I typically run the cable through the clamp body, then plug it into the Pico. If the head of the USB Micro end of the cable doesn't fit in the provided hole in the clamp body, then shave off some of the rubber at the head. To avoid exposing wires, give around a millimeter on all sides of the plug.

   The cable head doesn't fit through the Clamp Body:\
   Cable head does not fit

   \
   Shaving the cable head
   Shaved head
   Shaved head through Clamp Body
   
   From there, I normally have to use pliers to install the cable into the Pico due to the rubber head hitting the roof of the body.
   
   Attaching the cable head to the Pico with pliers

   Finally, I route the wires and attach the Clamp Body to the Left Body, securing it with the Clamp Port Cap.

   \
   Routing the cable
   Attaching Clamp Body
   Secure with Clamp Port Cap

   File down the Clamp Port Cap so that it will sit flush:\
   File down Clamp Port Cap so it sits flush
   
   #### Installing the Triggers and Thumbstick Cover
   
   To begin the process, I normally start with the Left Click Trigger, as it is the last piece needed to attach the two halves. The space between the end of the slide limiters and the electronic button is often slightly too long. In this case, cut off material from the tip until the trigger functions as intended.

   The tip of the Left Click Trigger is slightly too long\
   Why I needed to cut off the tip of the Left Click Trigger

   \
   Cutting off tip of Left Click Trigger
   Severed tip of Left Click Trigger
   Corrected fit of Left Click Trigger with Left Body
   
   From there, place the trigger in the half with all the electronics, and attach the other side.

   \
   Preparing to connect the two sides
   Two halves connected
   
   Assuming the trigger still works as desired and slides well, you can use the 3/4" screws to secure the two halves together.

   \
   Installing first screw
   All screws installed

   After both sides are attached, transition to the Right Click Trigger. The main point of struggle with this piece is the extender for the plunger. This part prints attached to a long handle for easier filing and adjustment. Using the handle, push the Plunger Extender into the hole on the left side of the body.
   
   Original Plunger Extender fit check using handle
   
   If any resistance is encountered, stop immediately, gently remove the extender and file down in the areas that were causing struggle.

   \
   Filing down Plunger Extender
   Re-checking Plunger Extender fit after filing
   
   Repeat this process as needed. Once the extender is satisfactory, cut off the handle and place the extender in the hole with the center of the torus segment facing the front of the device.

\
   Severing the handle from the Plunger Extender
   Installing the Plunger Extender in the hole with the torus diagram
   Plunger Extender fully installed
   
   Once this is complete, attach the Right Click Trigger as shown previously.

   \
   Installing Right Click Trigger
   Right Click Trigger installed

   Finally, it is time for the Thumbstick Cover. This part can be tricky to get right, but focus on not removing too much material from the hole in the Thumbstick Cover, else it will become wobbly during use. Align the hole of the cover with the stick of the Thumbstick, and try to press on. This takes some force, but if it will not attach, start removing material from the hole. The hole is ovular, so avoid using drills.

   Adjusting Thumbstick Cover
   
   If you printed this with less walls, the added flex of the material should assist with installation. If not, keep removing material until you are able to press the thumstick in place. Once installed, if you desire, you can add super glue to secure the cover.
   
   Thumbstick Cover fully installed

   #### Top Cover
   The final step is to attach the Top Cover. Align the screw holes with those on the body, and insert the screws. Before packing up your tools, make sure that the thumbstick moves with the desired freedom, the scroll wheel scrolls easily, and everything works correctly when plugged in to your computer.

## Final Results

Finished Project alone

Finished Project in hand

## Conclusion and Final Thoughts

Overall, this project has been a blast for me. I now have a working device that I can use as a mouse whenever I want to use my laptop on my lap. I accomplished what I set out to do. I have learned a lot through this project and there are many ways in which I would approach it differently were I to restart. While this is as far as I am willing to take the concept and project, my hope is that you or someone like you will find this project and modify it or use it as inspiration to create the next generation of Laptop Mouse Projects. If you choose to take that path, I would love if you would share it with me through GitHub. I hope that you have enjoyed this project as much as I have, and Happy Making!

This project is licensed under the [MIT License](LICENSE). See the [LICENSE-MIT](LICENSE-MIT) for further information.
All STL files and images are licensed under the [CC-BY-SA-4.0](LICENSE-CC-BY-SA-4.0). See [LICENSE-CC-BY-SA-4.0](LICENSE-CC-BY-SA-4.0)

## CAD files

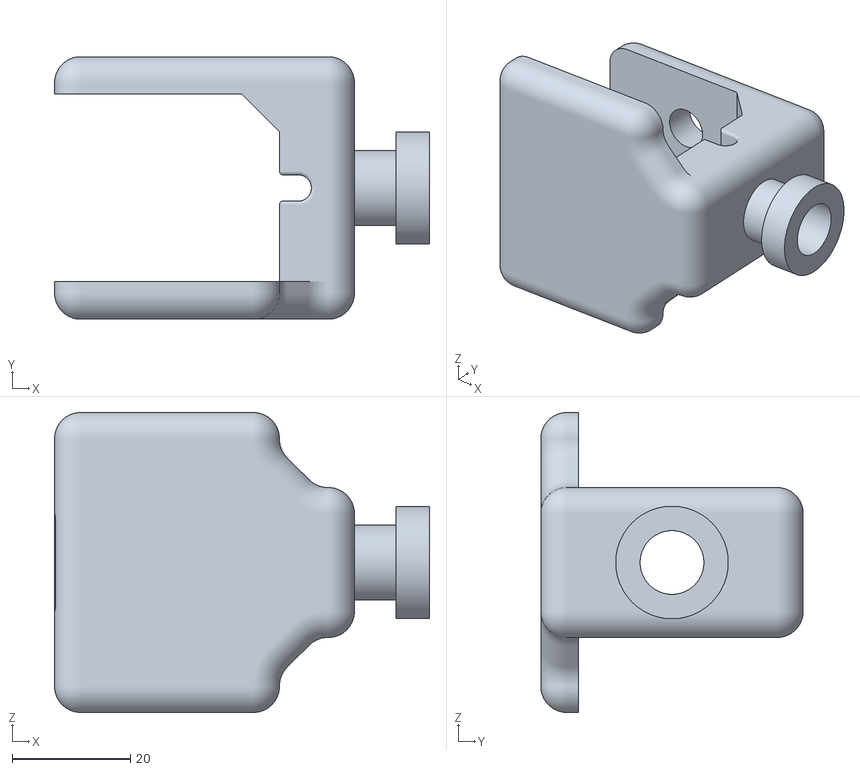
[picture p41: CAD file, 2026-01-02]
STLs/clamp-body.stl
63.5 x 44.4 x 50.8

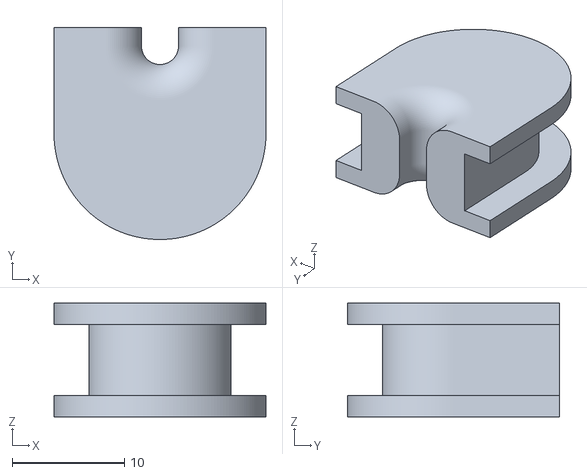
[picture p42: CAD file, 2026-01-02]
STLs/clamp-delete-plug-for-left-body.stl
18.9 x 18.9 x 10.2

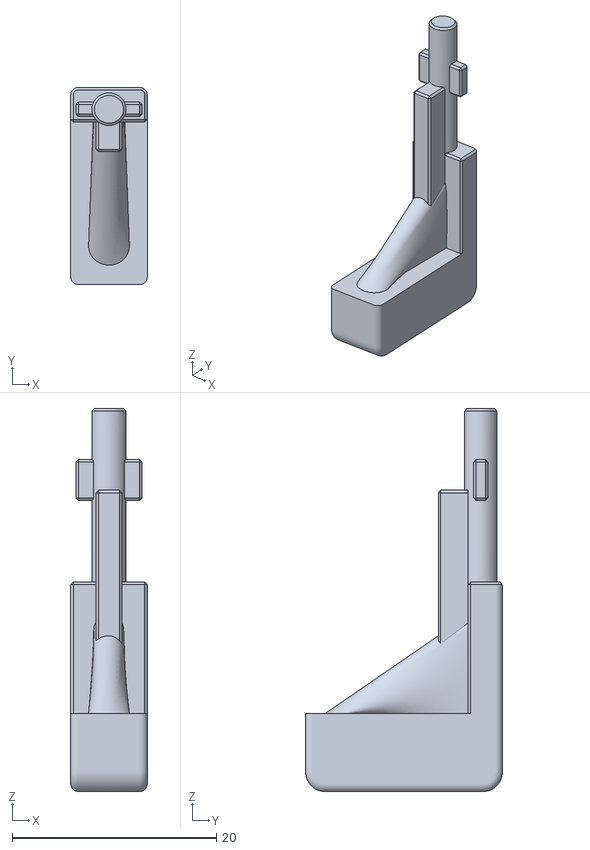
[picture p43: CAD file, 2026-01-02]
STLs/trigger-L-Click.stl
7.49 x 19.3 x 37.5

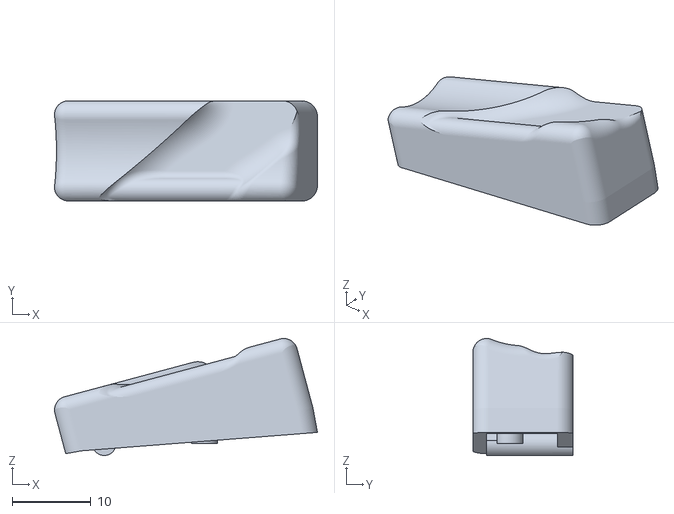
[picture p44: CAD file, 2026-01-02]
STLs/trigger-R-Click.stl
33.3 x 12.7 x 14.8

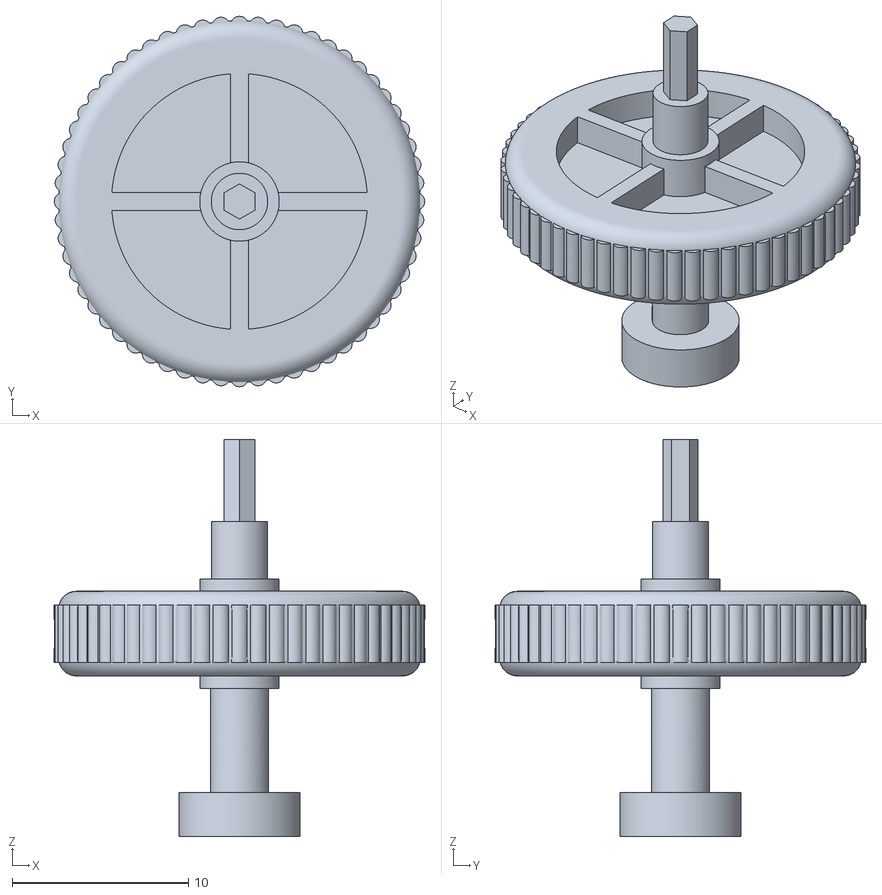
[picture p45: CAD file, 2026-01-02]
STLs/scroll-wheel.stl
21.0 x 21.0 x 22.5

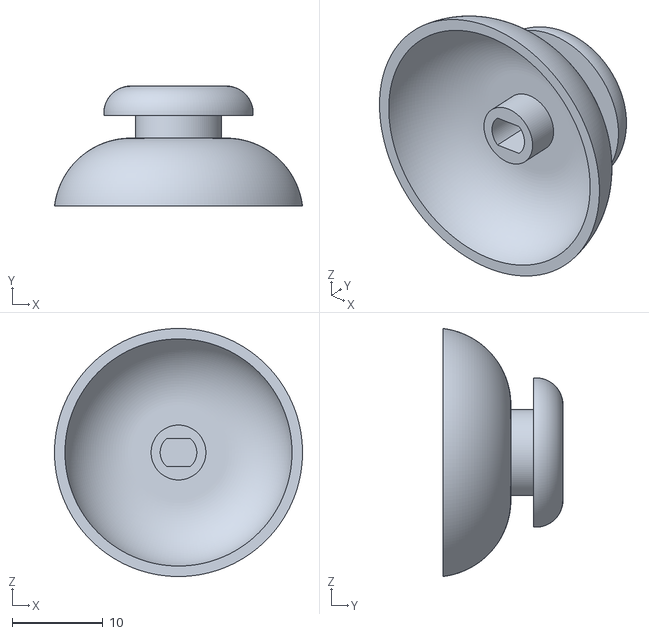
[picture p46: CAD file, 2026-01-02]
STLs/thumbstick-cap.stl
27.4 x 13.2 x 27.4

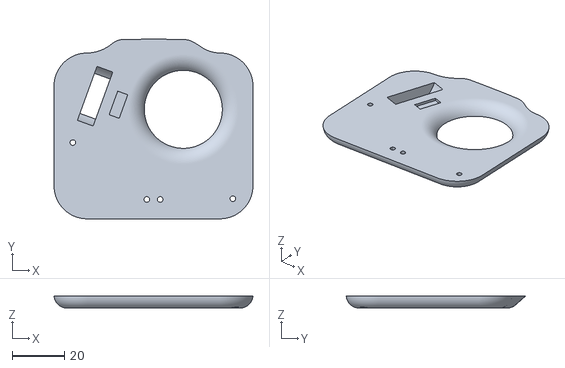
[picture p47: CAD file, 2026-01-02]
STLs/top-cover.stl
76.2 x 68.8 x 4.70

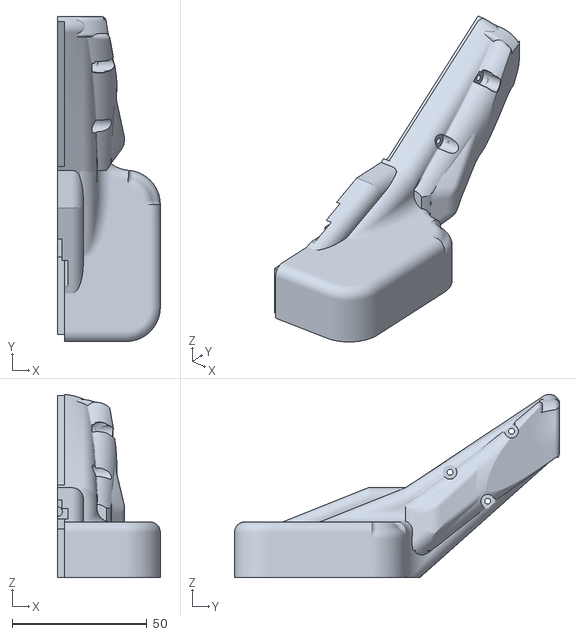
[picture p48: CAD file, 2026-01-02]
STLs/right-body.stl
38.1 x 120.7 x 68.1

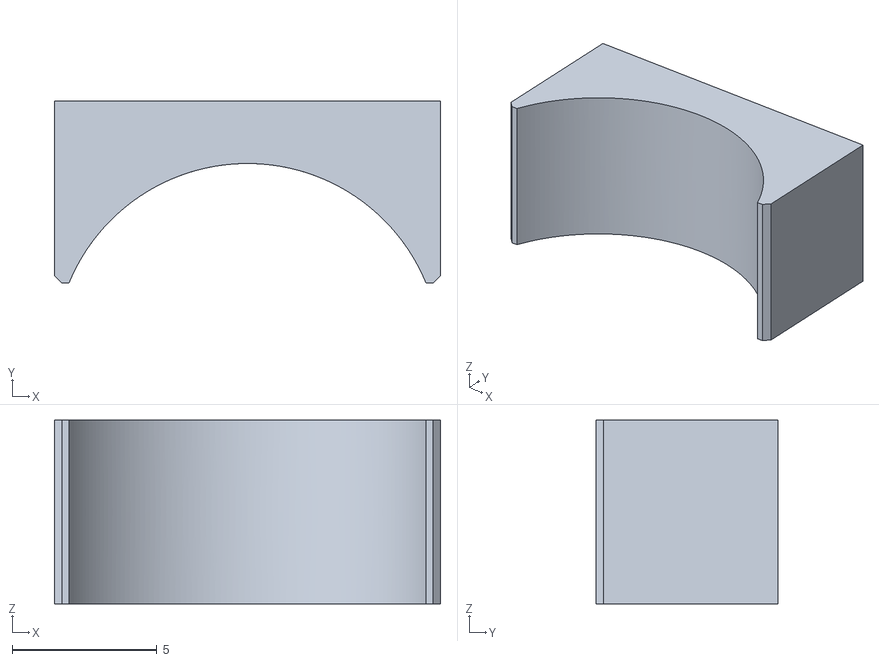
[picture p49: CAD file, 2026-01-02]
STLs/cap-for-clamp-port-on-left-body.stl
13.3 x 6.29 x 6.35

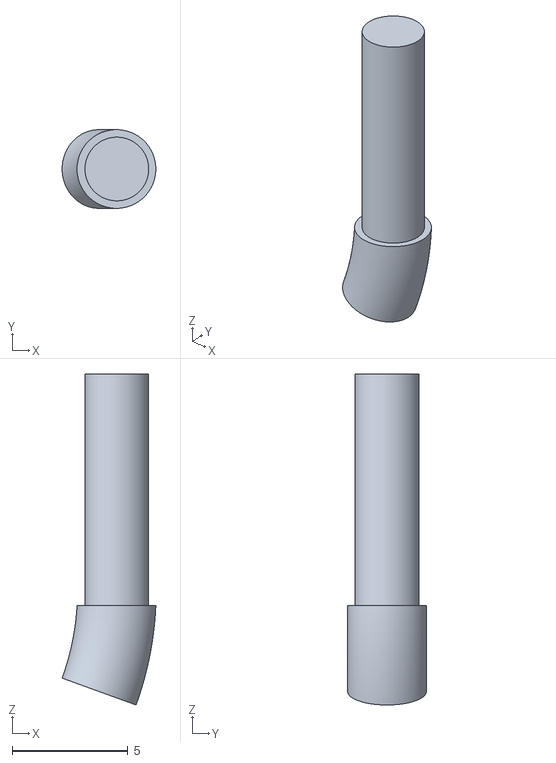
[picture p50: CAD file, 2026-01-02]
STLs/plunger-extender-for-trigger-R-Click.stl
4.05 x 3.40 x 14.3

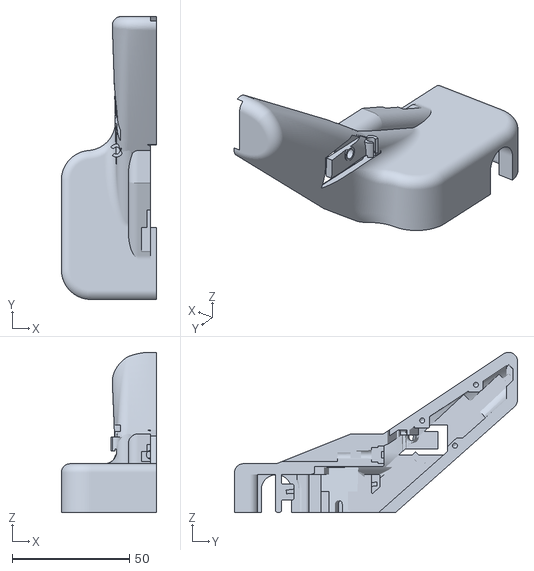
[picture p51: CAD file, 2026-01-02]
STLs/left-body.stl
40.6 x 120.7 x 68.4

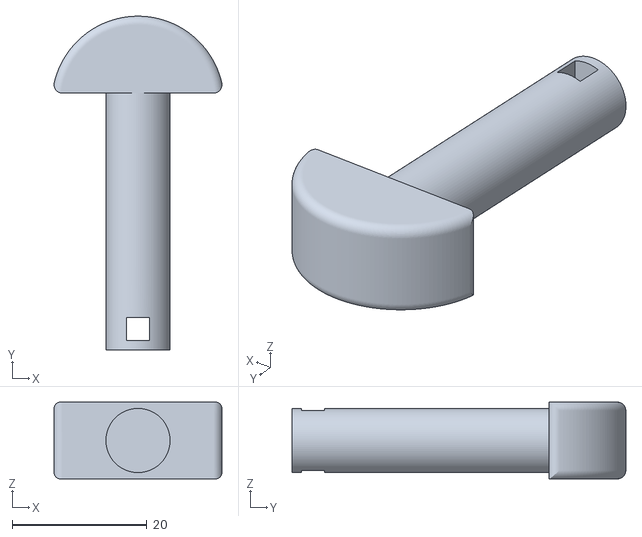
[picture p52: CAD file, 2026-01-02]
STLs/clamp-screw.stl
24.9 x 49.5 x 11.4

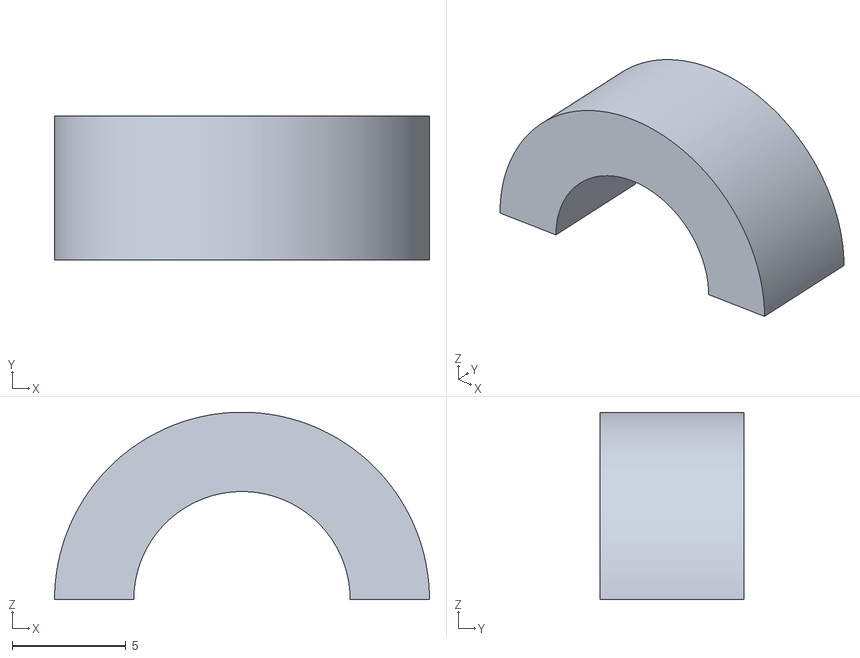
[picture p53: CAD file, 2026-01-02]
STLs/clamp-screw-bottom-F.stl
16.5 x 6.35 x 8.25

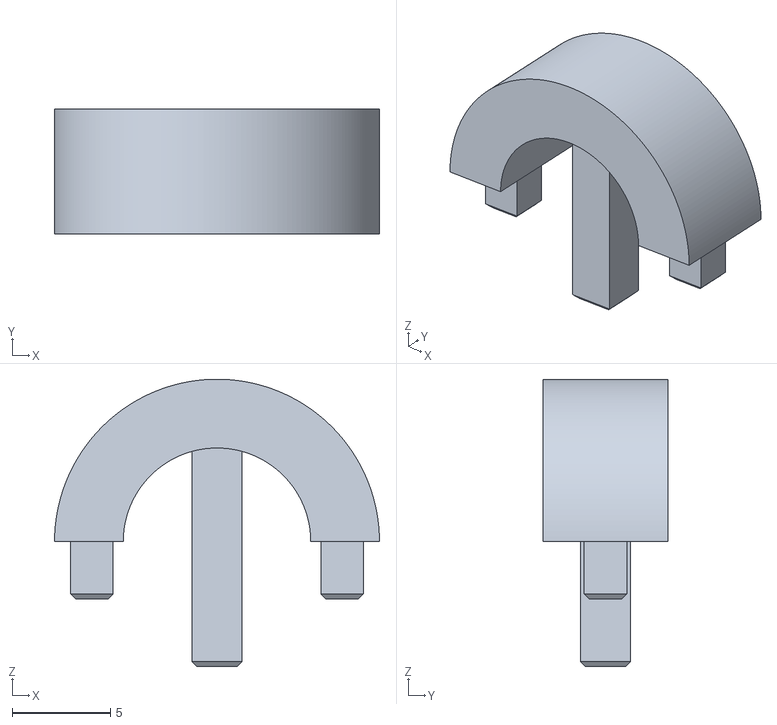
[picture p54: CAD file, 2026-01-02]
STLs/clamp-screw-bottom-M.stl
16.5 x 6.35 x 14.6

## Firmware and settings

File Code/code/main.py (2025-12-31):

"""
MIT License

Copyright (c) 2025 InsaneDev27

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
"""

import usb_hid
from adafruit_hid.mouse import Mouse
import time
import digitalio
import analogio
import rotaryio
import board

mouse = Mouse(usb_hid.devices)

lClick = digitalio.DigitalInOut(board.GP2)
lClick.switch_to_input(pull=digitalio.Pull.UP)
rClick = digitalio.DigitalInOut(board.GP3)
rClick.switch_to_input(pull=digitalio.Pull.UP)
cClick = digitalio.DigitalInOut(board.GP28)
cClick.switch_to_input(pull=digitalio.Pull.UP)

xRaw = analogio.AnalogIn(board.A1)
yRaw = analogio.AnalogIn(board.A0)
encoder = rotaryio.IncrementalEncoder(board.GP0, board.GP1, 1)

#variables for scroll and fast scroll functions
lastPosition = 0 # the last registered postion of the rotary encoder
lastTime = time.monotonic() # last time scroll wheel was moved
lastTimeFast = time.monotonic() # last time we scrolled speedily
lastTimeSet = time.monotonic() # last time the fast scrolling was initialized
lastScrollDirection = 1 # 1 for scrolling up, -1 for down
numOfIncrementsRecently = 0 # how many scroll wheel movements were registered recently ( within .03 seconds of each other )
encoderFactorBaseValue = 1
maxTimeBetweenIncrements = .01
maxTimeBetweenFastScroll = .6

tempDPI = False # temporary sensitivity for precision movements
dpi = 0.5 # sensitivity, not actual dpi measurement
encoderFactor = 2.0

lClickOn = False
rClickOn = False
cClickOn = False
dpiChangedThisPress = False

def get_voltage(raw):
    return (raw * 33) / 65536

def sameScrollDirection(deltaPosition):
    return ((lastScrollDirection == 1 and deltaPosition > 0) or (lastScrollDirection == -1 and deltaPosition < 0))

while True:
    deltaPosition = encoder.position - lastPosition;
    
    x=0
    y=0
    
    if (not tempDPI):
        x = int(int(get_voltage(xRaw.value) - 16.5) * dpi)
        y = int((int(get_voltage(yRaw.value) - 16.5) * dpi) * (-1)) #inverted out of neccessity
    else:
        x = int(int(get_voltage(xRaw.value) - 16.5) * .1)
        y = int((int(get_voltage(yRaw.value) - 16.5) * .1) * (-1))
        
    #     move(x, y,                wheel                )
    mouse.move(x, y, int((deltaPosition) * encoderFactor))

    #psuedo fast-scrolling (similar to how touchscreen scroll speed increases the more times in rapid succession the user scrolls)
    
    #making variables for the time elapsed since lastTime, lastTimeFast, and lastTimeSet were updated
    currTime = time.monotonic()
    timeSinceLast = currTime - lastTime
    timeSinceLastFast = currTime - lastTimeFast
    timeSinceLastSet = currTime - lastTimeSet
    
    # if any scroll wheel movement registered
    if (int(deltaPosition) != 0):
        # UNCOMMENT BELOW if you want data on scroll speed to adjust time settings for your preferences
        #print("num of increments: ", numOfIncrementsRecently, " lastTime: ", timeSinceLast, " lastTimeFast: ", timeSinceLastFast, " lastTimeSet: ", timeSinceLastSet, " encoderFactor: ",  encoderFactor)
        
        # if this change was close in time to the last, and the scroll direction has not changed
        if (timeSinceLast <= maxTimeBetweenIncrements and sameScrollDirection(deltaPosition)): # (doesn't register anything in between 1 and zero)
            numOfIncrementsRecently += 1
            # increase encoder factor to 1.5 to give a more horsepower at the start
            if (encoderFactor == encoderFactorBaseValue):
                # this declares the last time that fast scrolling started is now
                lastTimeSet = time.monotonic()
            # we just went fast, so set lastTimeFast to now
            lastTimeFast = time.monotonic()

            # after horsepower boost, if still eligible, feel free to keep increasing within the limit of 10x speed
            if((numOfIncrementsRecently > 1) and (timeSinceLastFast <= maxTimeBetweenFastScroll)):
                if (encoderFactor <= 10):
                    encoderFactor = encoderFactor + .5
                numOfIncrementsRecently = 0
            # we just went fast, so set lastTimeFast to now
            lastTimeFast = time.monotonic()
        # elif ineligible to go fast
        elif (((timeSinceLastFast > maxTimeBetweenFastScroll) and (timeSinceLastSet >= 1)) or not sameScrollDirection(deltaPosition)):
            numOfIncrementsRecently = 0
            encoderFactor = encoderFactorBaseValue
            
        #we recieved scroll wheel input, so we will update lastTime to match
        lastTime = currTime
        
        #updating lastScrollDirection to match new direction regardless if different or just ran out of time.
        if (deltaPosition < 0):
            lastScrollDirection = -1
        else:
            lastScrollDirection = 1
            
    lastPosition = int(encoder.position) #hopefully this will not reset the last position until it has been registered in mouse.move()
    
    # the .value properties of the buttons are inversely assigned (pushed is registered as false), so this code makes it easier to read
    lCV = not lClick.value
    rCV = not rClick.value
    cCV = not cClick.value
    
    # if all 3 buttons pressed, change dpi
    if lCV and rCV and cCV and not dpiChangedThisPress:
        if (dpi != 2.0):
            dpi += 0.5
        else:
            dpi = 0.5
        
        # do no other functions on this press
        dpiChangedThisPress = True
    
    # if left and right click pressed, engage temporary DPI
    elif (lCV and rCV and not dpiChangedThisPress):
        tempDPI = not tempDPI
        dpiChangedThisPress = True
                 
    elif (not dpiChangedThisPress):
        # if not being held, send left click input to computer:
        if lCV and not lClickOn:
            mouse.press(mouse.LEFT_BUTTON)
            lClickOn = True
              
        # if not being held, send right click input to computer:
        if rCV and not rClickOn:
            mouse.press(mouse.RIGHT_BUTTON)
            rClickOn = True      
        
        # if not being held, send center click input to computer:
        if cCV and not cClickOn:
            mouse.press(mouse.MIDDLE_BUTTON)
            cClickOn = True
    
        
    # release if not being pressed
    if not lCV and lClickOn:
        lClickOn = False
        dpiChangedThisPress = False
        mouse.release(mouse.LEFT_BUTTON)
    if not rCV and rClickOn:
        rClickOn = False
        dpiChangedThisPress = False
        mouse.release(mouse.RIGHT_BUTTON)
    if not cCV and cClickOn:
        cClickOn = False
        dpiChangedThisPress = False
        mouse.release(mouse.MIDDLE_BUTTON)
        
    #FAILSAFE
        #if you are stuck, press ctrl+c to stop program
        
    
    time.sleep(0.001)

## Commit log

2025-11-26 Electronics and Assembly Images
2025-11-26 right click button images as test
2025-11-27 Create Rotary Encoder diagram to cut off extra legs.jpg
2025-11-27 Create Pi Pico Pinout for LMP.jpg
2025-11-27 Create Alternative Ground Position on Pico.png
2025-12-08 Images for scroll wheel and clamp body added
